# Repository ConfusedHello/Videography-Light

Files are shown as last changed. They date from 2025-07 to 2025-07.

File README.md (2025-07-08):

# LUXCRAFT - DIY Film Light
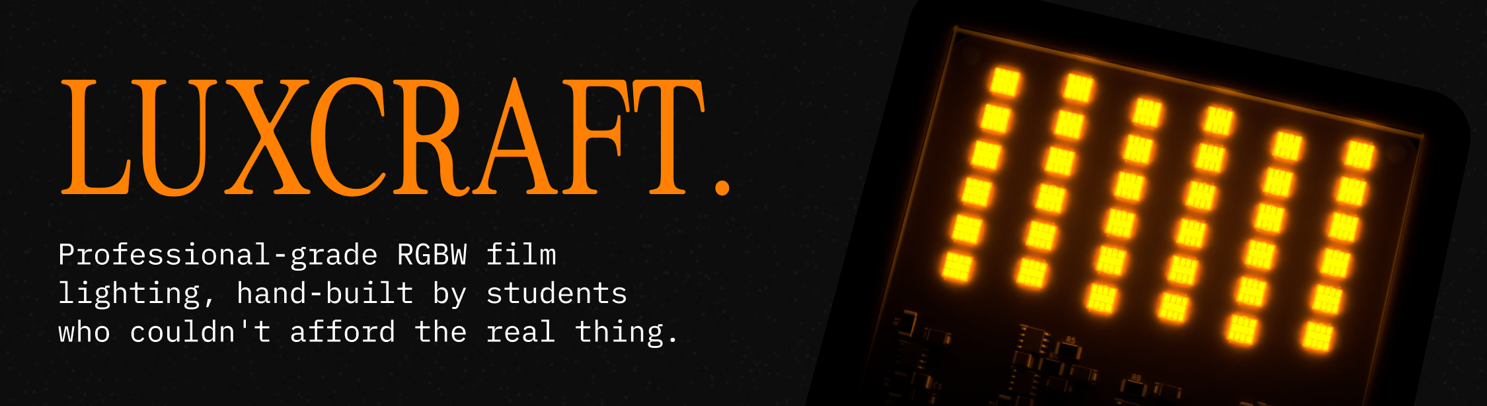
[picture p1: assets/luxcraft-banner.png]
Banner


Ever wanted a videography light but died when seeing the insane prices? Me too! This project involves a DIY, high-power RGBW film light built by [@ConfusedHello](https://github.com/confusedhello) and [@Jayx2u](https://github.com/Jayx2u/) for the Hack Club [Highway to Hardware](https://highway.hackclub.com/) program!

We decided to design this project because as students, we honestly don't have the spare cash lying around for one, and we wanted a nice accent light for our planned upcoming videos. It utilises 36 *current controlled* RGBW LEDs running off a 48V supply and controlled with a Xiao RP2040!

For details about the design process or other information, check out the [development journal](https://highway.hackclub.com/projects/ConfusedHello/Videography-Light). A local copy is available in [JOURNAL.md](https://github.com/ConfusedHello/Videography-Light/blob/main/JOURNAL.md).

## The Design
Here's a quick diagram showing how the project works~
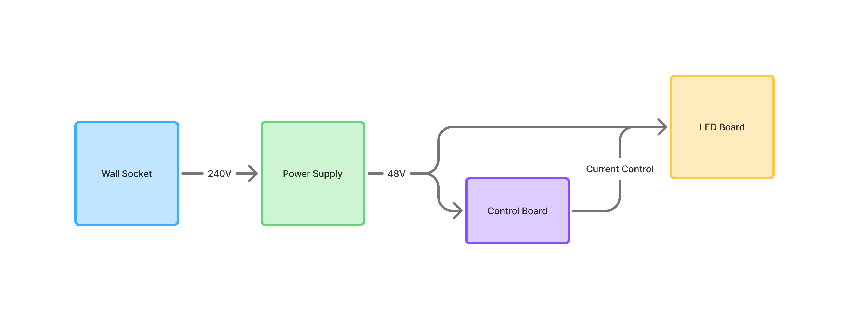
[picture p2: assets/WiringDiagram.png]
Wiring Diagram


And a nice rendered image of the case and control board-
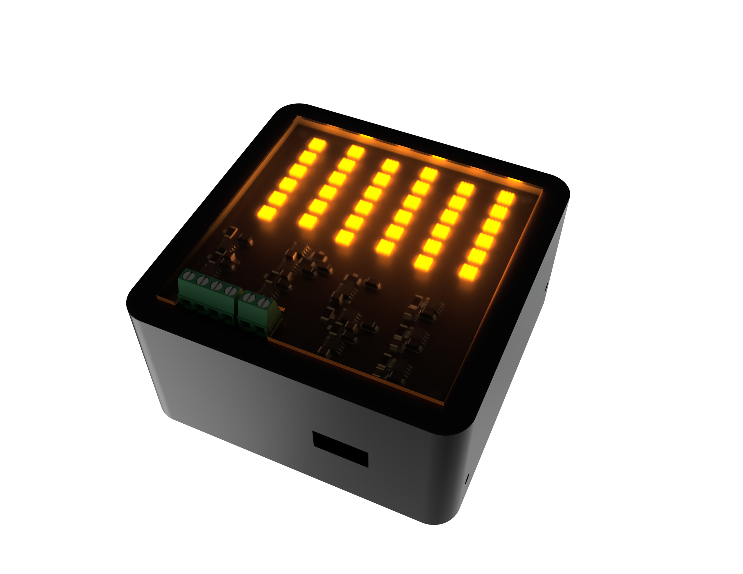
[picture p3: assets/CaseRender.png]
Case Render

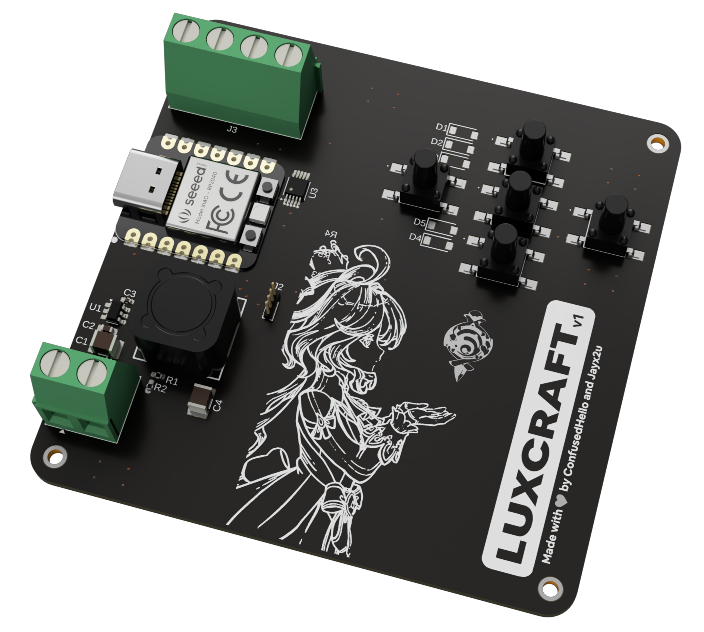
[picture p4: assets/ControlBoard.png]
Control Board


As well as the schematic and PCB for both the control and light boards!
Schematic and PCB for both boards

Also the CAD because apparently that's necessary.
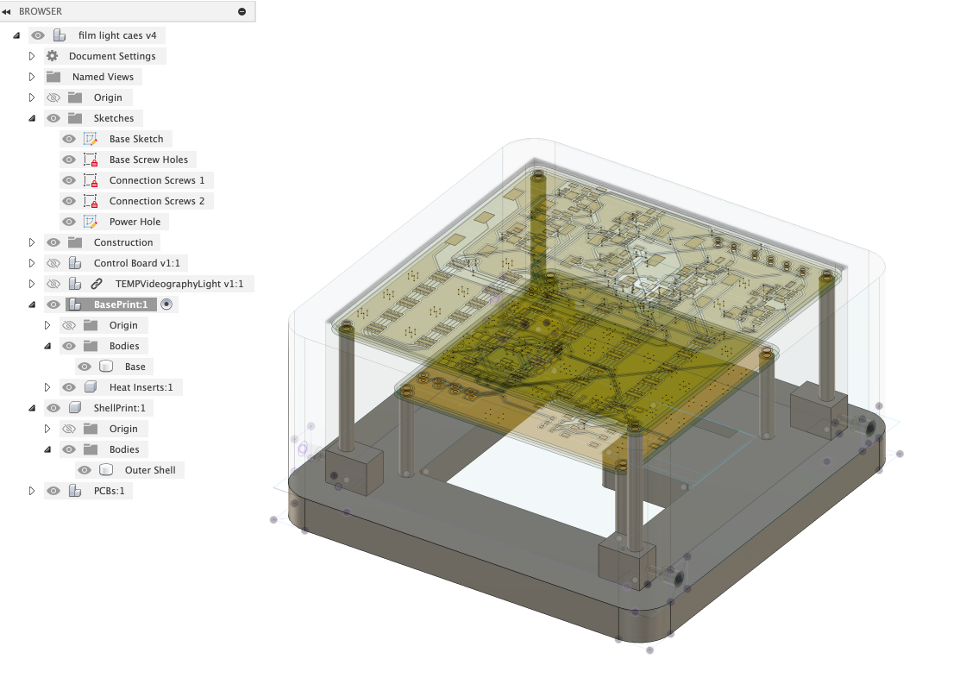
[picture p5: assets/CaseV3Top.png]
CAD
 

## Bill of Materials
Also available in .csv format in [BOM.csv](https://github.com/ConfusedHello/Videography-Light/blob/main/BOM.csv)! BOMs for the PCBs are in [ControlBoard.csv](https://github.com/ConfusedHello/Videography-Light/blob/main/src/Production/Control%20PCB/ControlBoard.csv) and [VideographyLight.csv](https://github.com/ConfusedHello/Videography-Light/blob/main/src/Production/Light%20PCB/VideographyLight.csv)~

|Item |Qty.|Price (USD)|Ext. (USD)|Link |
|---|----|---|---|---|
|997-L1MCRGB2295MP0 |36  |$1.36 |$48.96 |https://mouser.com/c/?q=997-L1MCRGB2295MP0 |
|81-GRM32EC72A106ME5K |11  |$0.71 |$7.85 |https://mouser.com/c/?q=81-GRM32EC72A106ME5K |
|710-7447706101 |11  |$1.01 |$11.11 |https://mouser.com/c/?q=710-7447706101 |
|71-WSLT2010R5000FEA1 |11  |$0.57 |$6.28 |https://mouser.com/c/?q=71-WSLT2010R5000FEA1 |
|625-SS1H10-E3 |11  |$0.28 |$3.11 |https://mouser.com/c/?q=625-SS1H10-E3 |
|621-AL8862SP-13 |11  |$0.54 |$5.93 |https://mouser.com/c/?q=621-AL8862SP-13 |
|179-TB0012-508-04GR |2 |$1.29 |$2.58 |https://mouser.com/c/?q=179-TB0012-508-04GR |
|179-TB0012-508-02GR |2 |$0.69 |$1.38 |https://mouser.com/c/?q=179-TB0012-508-02GR |
|579-MCP4728-E/UN |1 |$2.50 |$2.50 |https://mouser.com/c/?q=579-MCP4728-E/UN |
|713-102010428 |1 |$5.40 |$5.40 |https://mouser.com/c/?q=713-102010428 |
|595-LMR51606XFQDBRQ1 |1 |$2.25 |$2.25 |https://mouser.com/c/?q=595-LMR51606XFQDBRQ1 |
|179-TS046695BK100SMT |5 |$0.16 |$0.80 |https://mouser.com/c/?q=179-TS046695BK100SMT |
|71-CRCW12104K70JNAIF |2 |$0.58 |$1.16 |https://mouser.com/c/?q=71-CRCW12104K70JNAIF |
|71-CRMA1210AF100KFKF |1 |$0.85 |$0.85 |https://mouser.com/c/?q=71-CRMA1210AF100KFKF |
|71-CRCW0402-19.1K-E3 |1 |$0.10 |$0.10 |https://mouser.com/c/?q=71-CRCW0402-19.1K-E3 |
|71-CRCW0402-100K-E3 |1 |$0.10 |$0.10 |https://mouser.com/c/?q=71-CRCW0402-100K-E3 |
|70-IFDC5050JZER470M |1 |$0.96 |$0.96 |https://mouser.com/c/?q=70-IFDC5050JZER470M |
|637-1N4148W |5 |$0.10 |$0.50 |https://mouser.com/c/?q=637-1N4148W |
|810-C3225X7R1H106MAC |2 |$0.96 |$1.92 |https://mouser.com/c/?q=810-C3225X7R1H106MAC |
|81-GRM155R71C104KA88 |2 |$0.10 |$0.20 |https://mouser.com/c/?q=81-GRM155R71C104KA88 |
|81-GRM188R72A104KA35 |1 |$0.15 |$0.15 |https://mouser.com/c/?q=81-GRM188R72A104KA35 |
|581-KAM32LR72A475KU |1 |$0.91 |$0.91 |https://mouser.com/c/?q=581-KAM32LR72A475KU |
|Aluminum Heatsink |10  |$0.73 |$7.33 |https://www.aliexpress.com/item/4000723868050.html |
|0.96 Inch OLED Display |1 |$2.60 |$2.60 |https://www.aliexpress.com/item/1005007614149117.html|
|M2 Heat Insert |16  |$0.11 |$1.73 |https://www.aliexpress.com/item/1005003582355741.html|
|M2 Screw (10mm) |16  |$0.21 |$3.40 |https://www.aliexpress.com/item/1005005688616965.html|
|48V Power Supply |1 |$25.73 |$25.73 |https://www.aliexpress.com/item/1005008528926877.html|
|JLCPCB Control Board |1 |$2.00 |$2.00 |https://www.jlcpcb.com |
|JLCPCB Light Board |1 |$2.00 |$2.00 |https://www.jlcpcb.com |
|JLCPCB Light Board Stencil|1 |$7.00 |$7.00 |https://www.jlcpcb.com |
|JLCPCB Shipping |1 |$21.22 |$21.22 |https://www.jlcpcb.com |

**Total:** $178.01 USD

<hr>

Made with ❤️ by [@ConfusedHello](https://github.com/confusedhello) and [@Jayx2u](https://github.com/Jayx2u/)

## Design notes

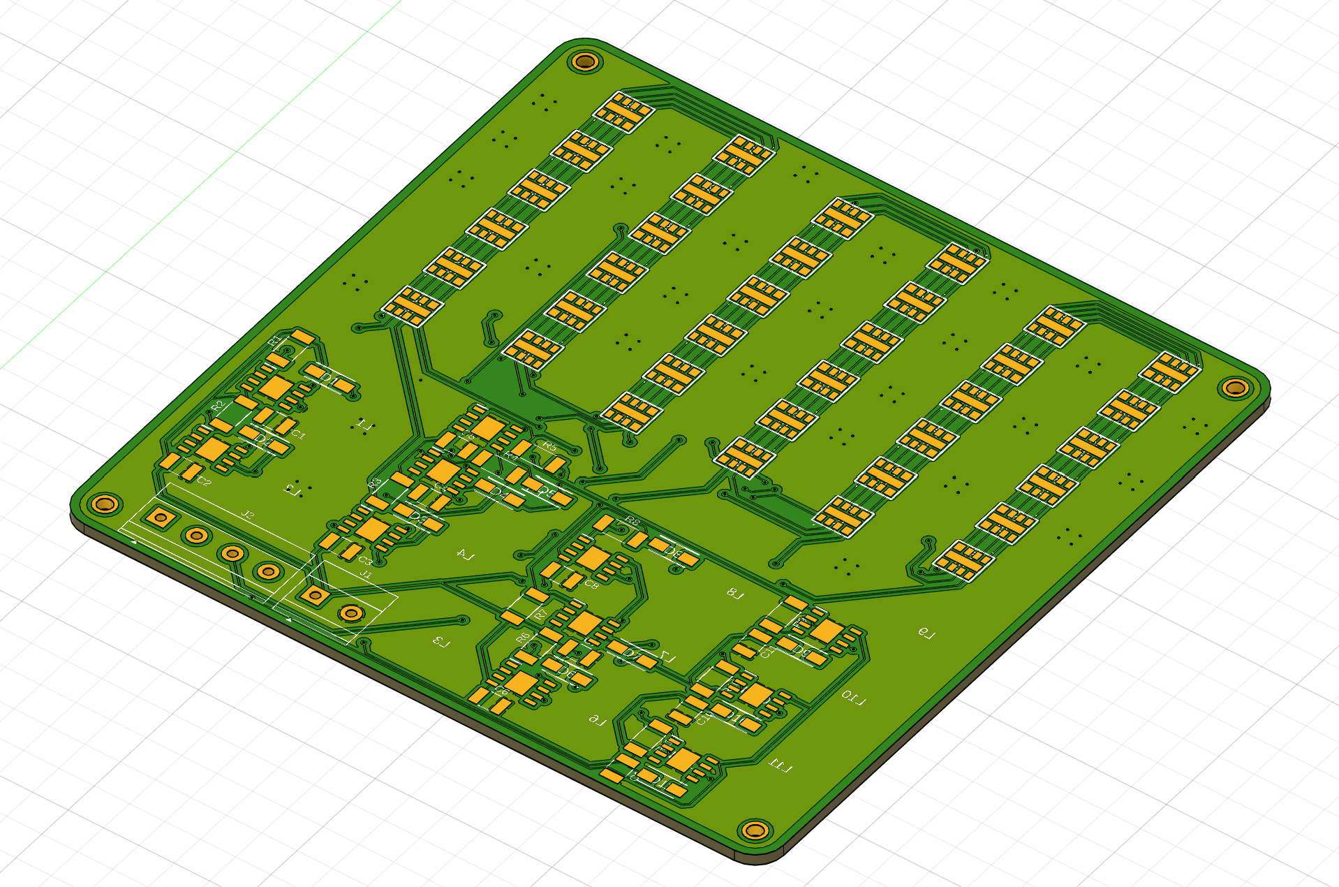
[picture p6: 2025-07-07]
assets/FusionPCB1.png

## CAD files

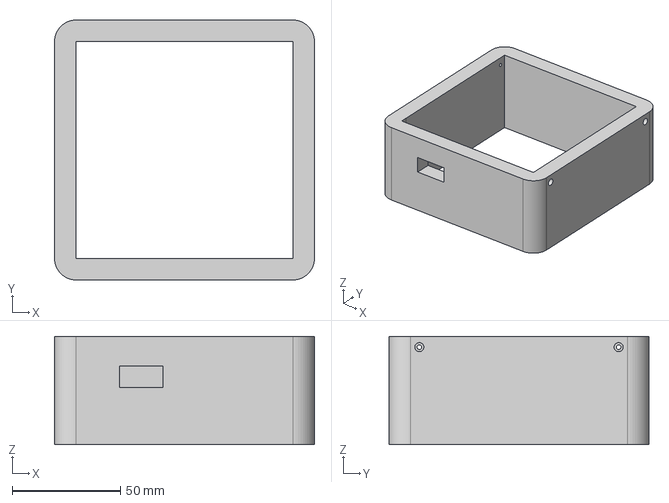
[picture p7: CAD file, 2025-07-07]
src/CAD/ShellPrint.step
120.0 x 120.0 x 50.0 mm

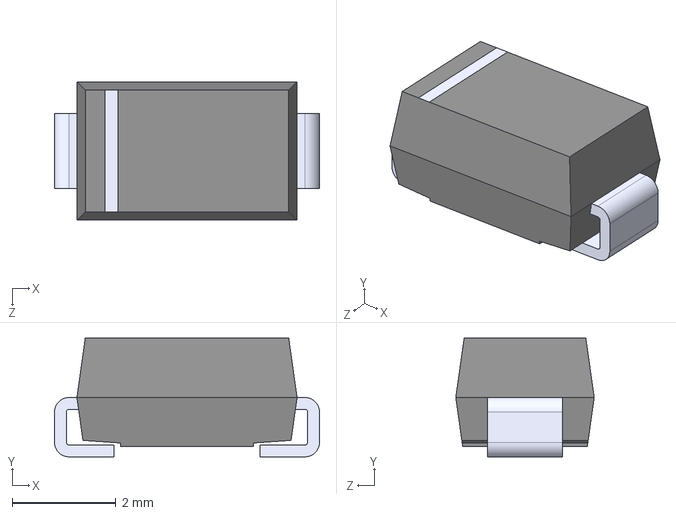
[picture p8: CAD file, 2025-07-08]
src/PCB/VideographyLight/footprints/models/SS1H10-E3_61T.stp
5.11 x 2.29 x 2.67 mm

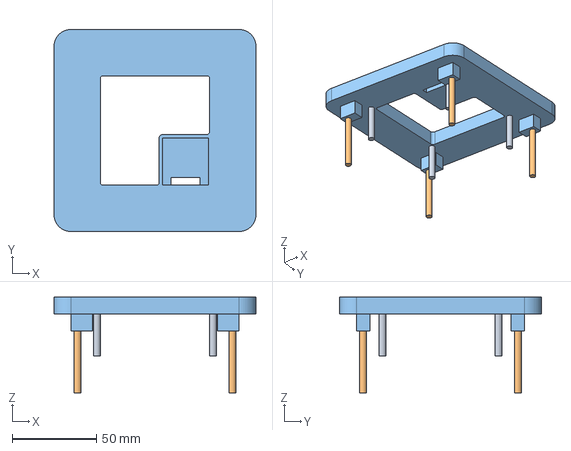
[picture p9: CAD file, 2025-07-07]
src/CAD/BasePrint.step
120.0 x 120.0 x 56.9 mm

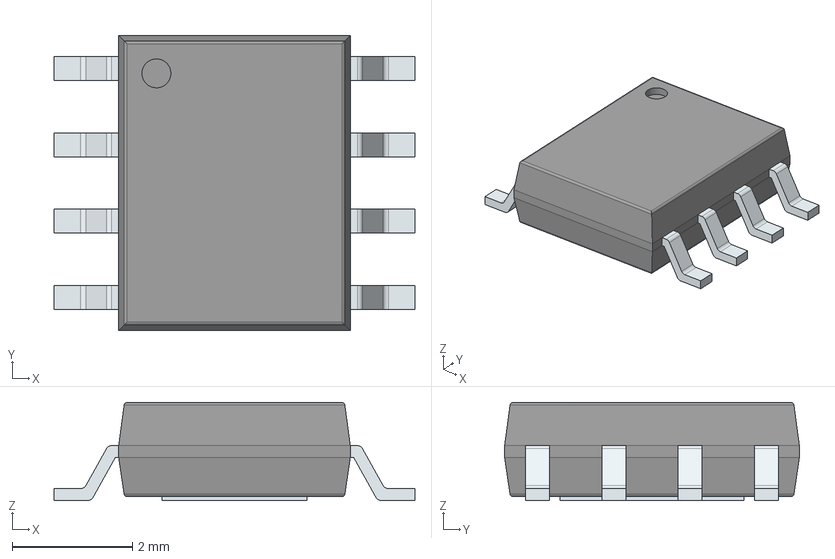
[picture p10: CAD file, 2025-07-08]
src/PCB/VideographyLight/footprints/models/AL8862SP-13.stp
6.00 x 4.90 x 1.63 mm
PinsArrayLR
ThermalPad

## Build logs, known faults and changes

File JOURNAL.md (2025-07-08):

---
title: "Videography Light"
author: "ConfusedHello, Jayx2u"
description: "A DIY Film Light for Videography!"
created_at: "2025-06-29"
---

**Total time spent: 66hrs**

## July 8th
Final preparations for submission! Did some silkscreening for the control PCB, made a quick flowchart for the wiring, finished up the BOM, rendered out some nice images for the README, and well, wrote the README all in time for a note-so-late night submission (woah not 1AM really?).

**Time spent: 7hrs**

## July 7th - @Jayx2u
With the PCB design completed, it was time for the case. I had the incredibly innovative never-seen before idea of placing a cube (with round corners of course) around all the electronics and calling it a day. Shocking and genius idea I know right, no need to thank me. ;)

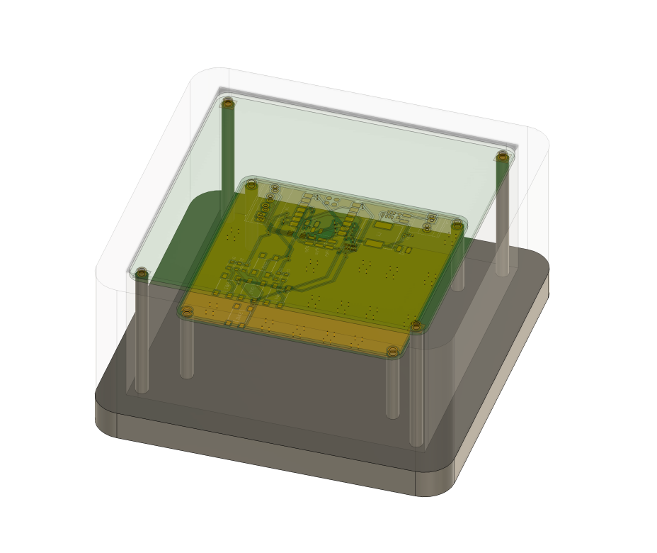
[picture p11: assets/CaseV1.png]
Case v1

Annnnnd volia! A cube around the whole thing. Has ample space for all the components and the heatsink. The translucent component is the shell and the rest is the base. Printed in to different parts. 

Then it hits me 🤸🏌️. How do I attach the base to the shell??? So voila again, version 2, but with four screw holes in the shell and 4 heat insert areas on the base.

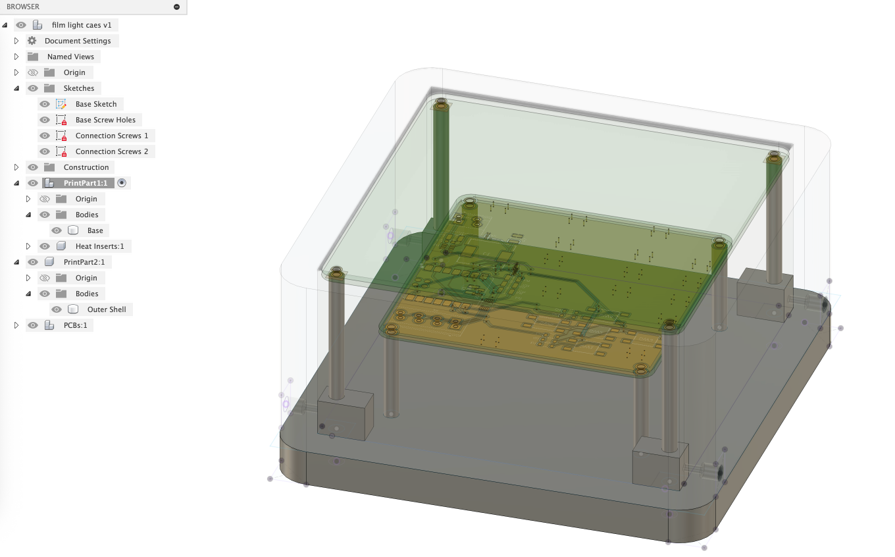
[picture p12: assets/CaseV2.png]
Case v2


Then it runs into me (again I know) 🤸🚗. How do I access the buttons on the bottom of the control PCB? Where's the OLED screen's location?? How does the power cables go into the case and connect to the control PCB??? So onto version 3 (aka final-final-this-time-for-real-film-light-caes.f3d). I decided to just put a hole in the bottom (with curved edges of course) and also include the place the OLED will be down there too. Also put a hole in the side for the power cables to enter. Here is what the base sketch ended up looking like - wanted it very precise:

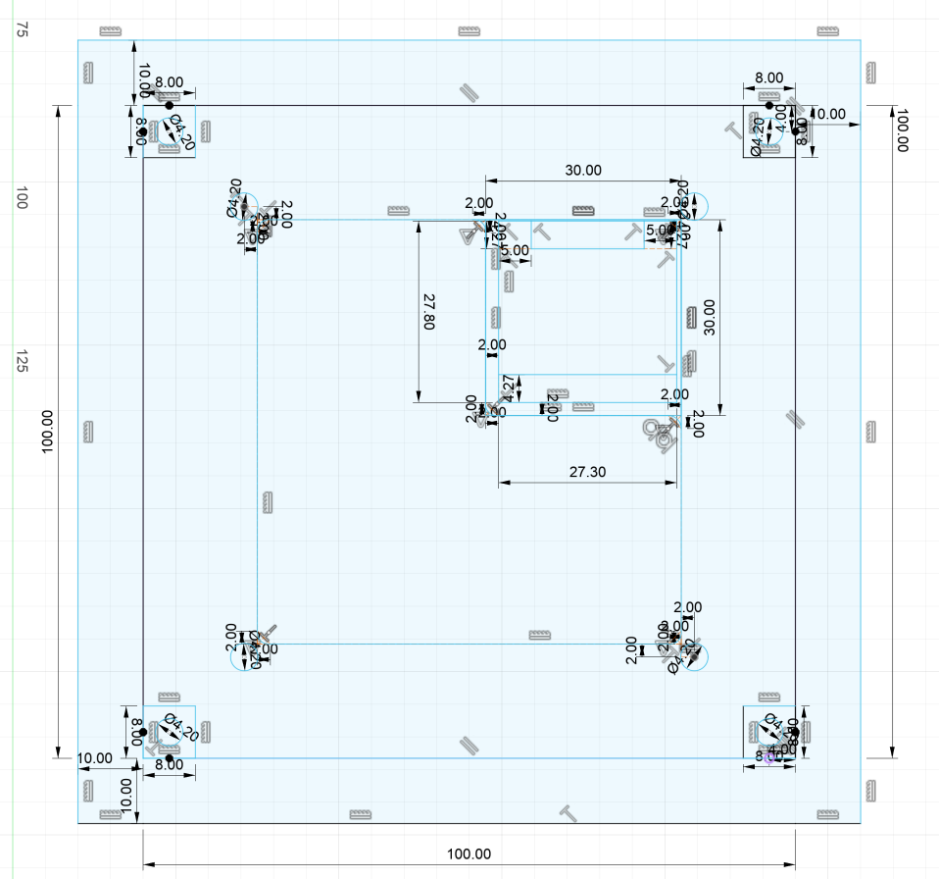
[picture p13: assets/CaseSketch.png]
Case Sketch


And with that.... tadaaaa version 3:

Case v3 Top
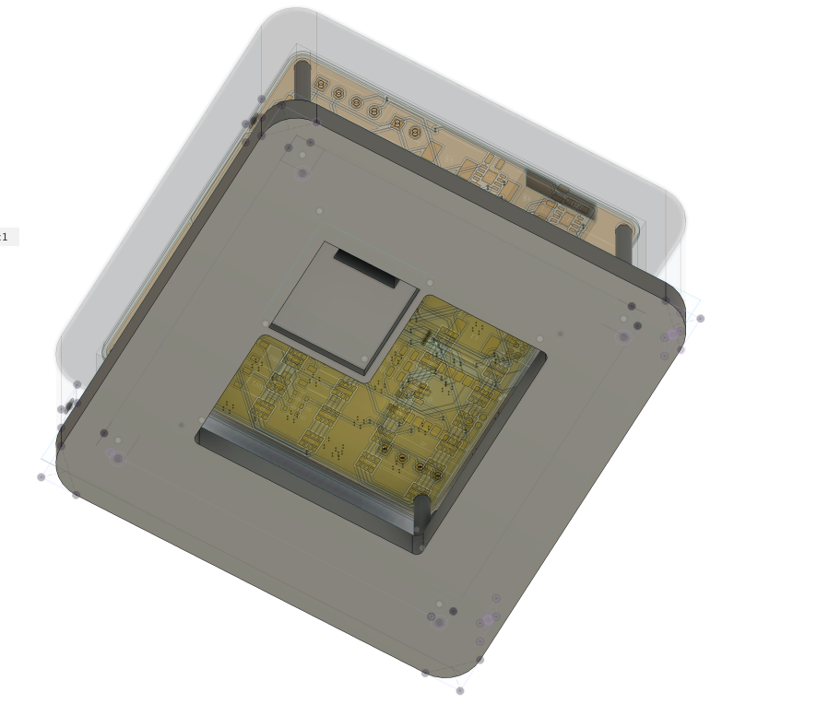
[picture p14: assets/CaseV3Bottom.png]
Case v3 Bottom


**Time spent: 2hrs**

## July 3rd, 4th, 7th - @ConfusedHello
Finished off the light PCB!! Here's some screenshots to conclude my development journaling! There's actually better images in the [README](https://raw.githubusercontent.com/ConfusedHello/Videography-Light/) with silkscreens~

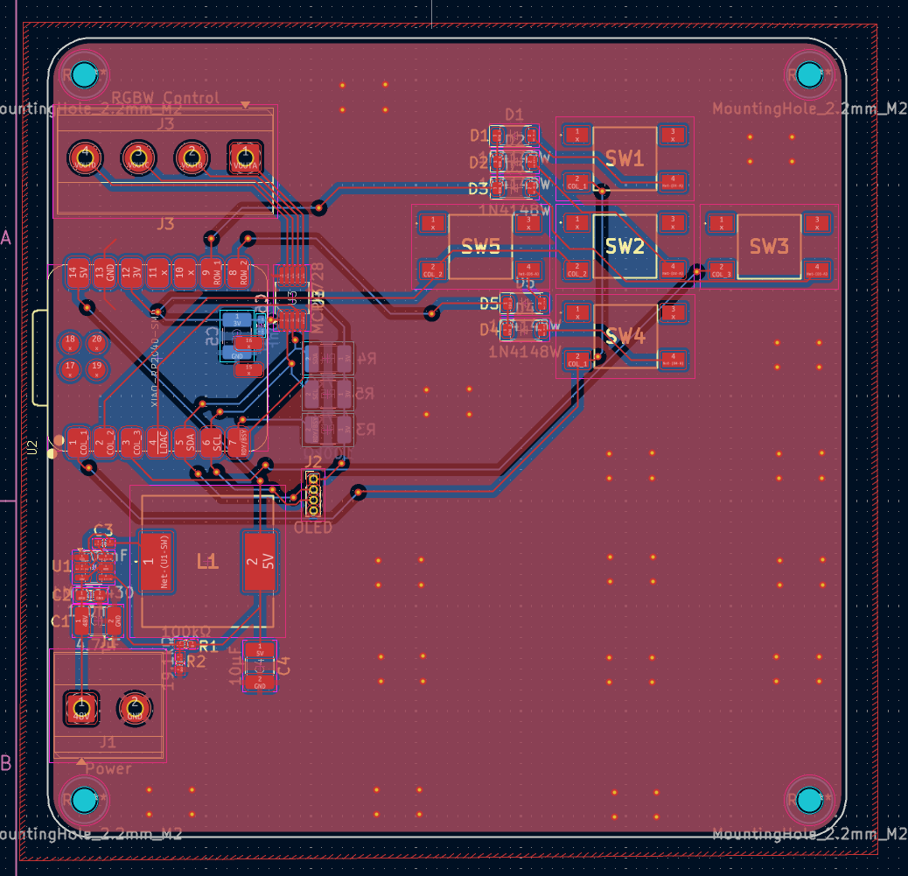
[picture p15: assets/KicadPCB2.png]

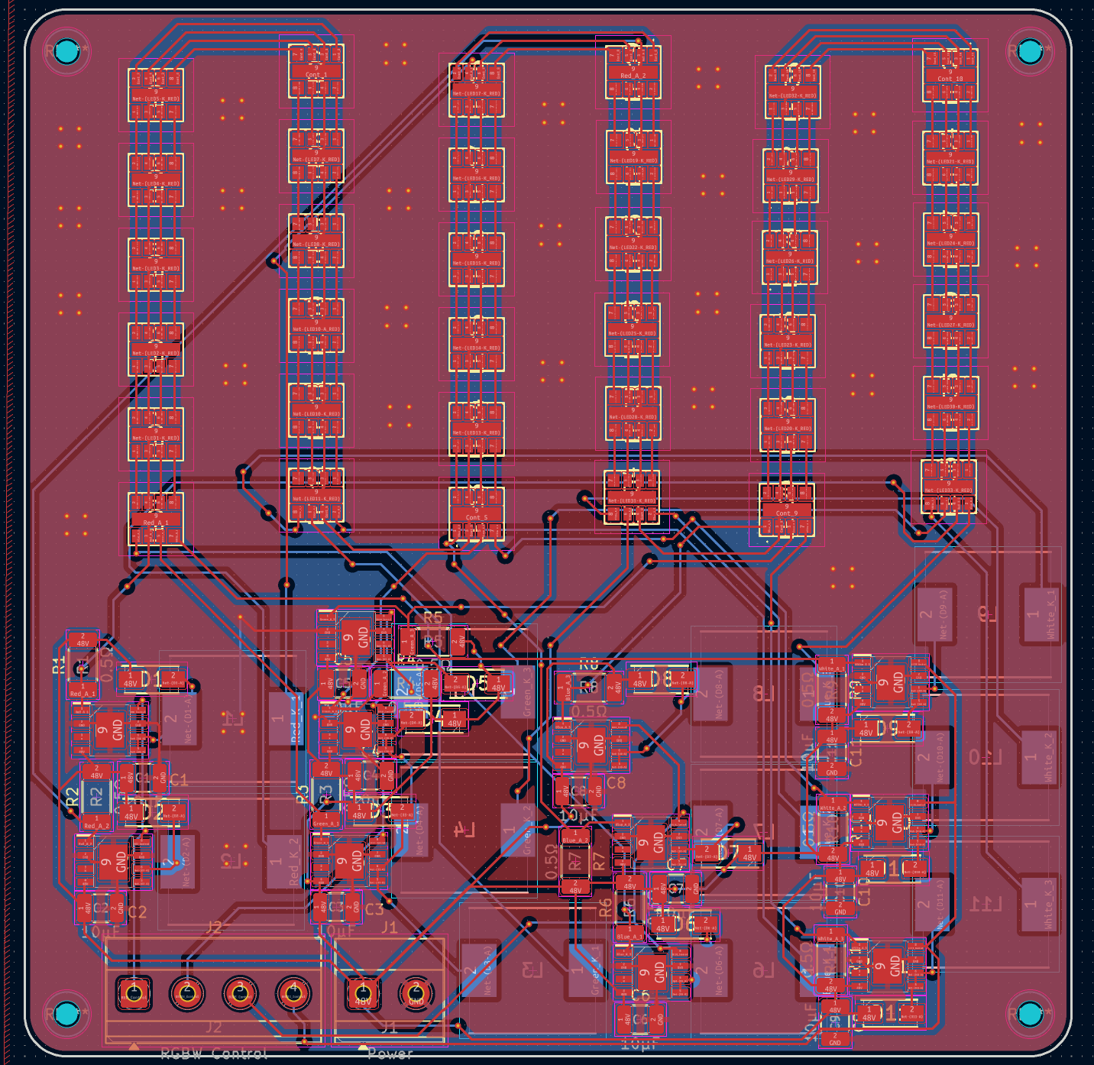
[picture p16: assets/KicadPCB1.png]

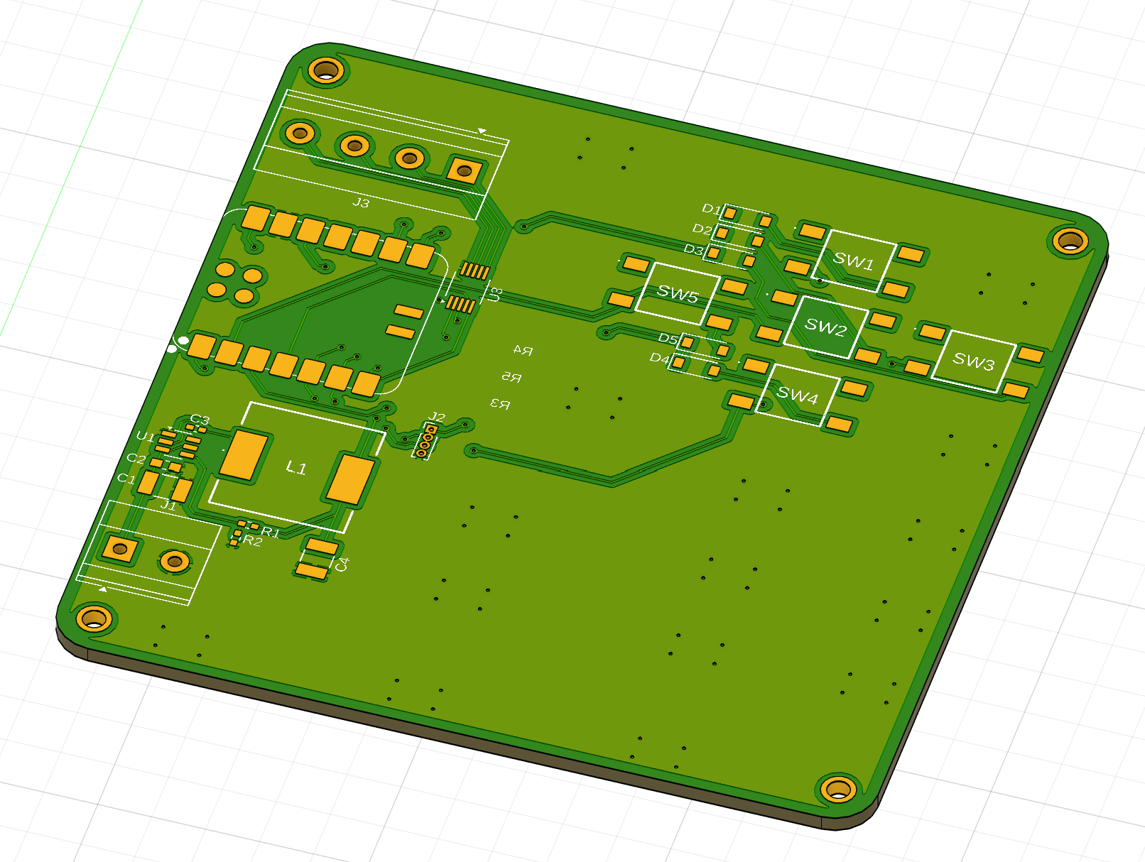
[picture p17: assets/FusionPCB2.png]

PCB

Finishing off the PCB was not particularly easy but it (hopefully) should be functional! Here's some crazy routing (with the GND plane removed)

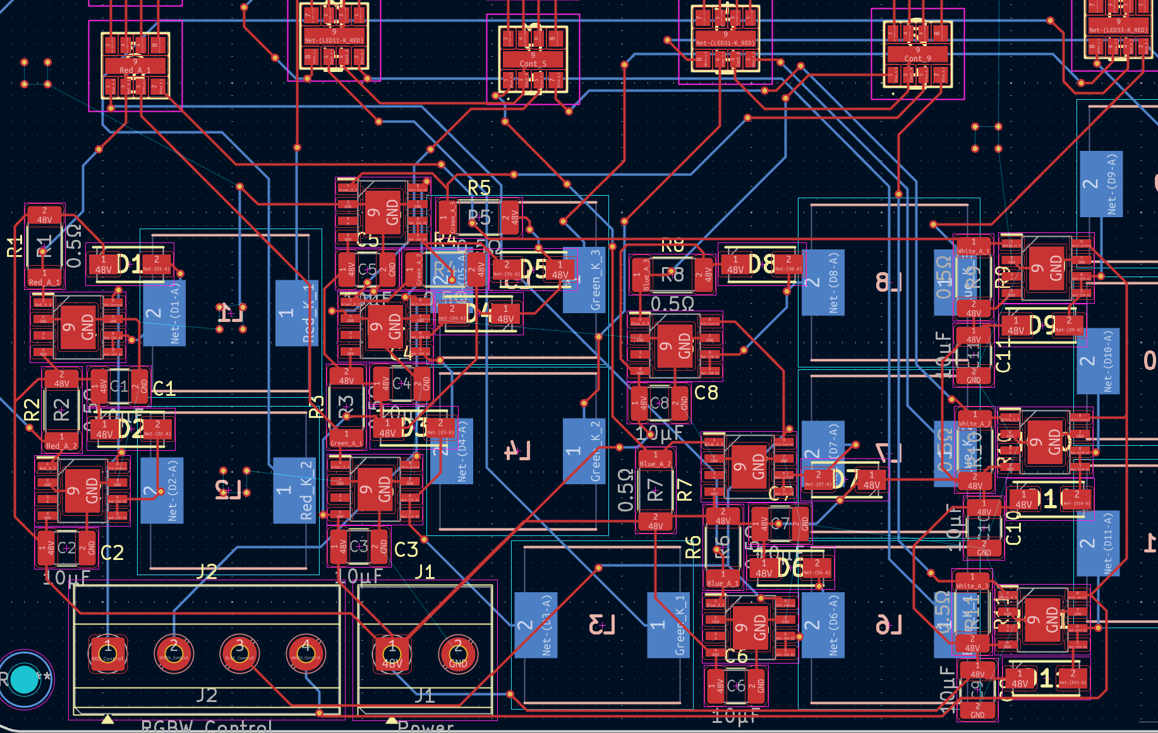
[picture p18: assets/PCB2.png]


**Time spent: 22hrs**

## July 2nd - @ConfusedHello
Another full day spent on the project - practically the entire day from waking up to going to sleep. Made the control board schematic and PCB today!

The control board will use a XIAO RP2040 MCU, along with a DAC for precise RGBW intensity control (voltage control). The PCB layout for this board was honestly not the worst I've done. There's also a 5V regulator circuit for the MCU and DAC.

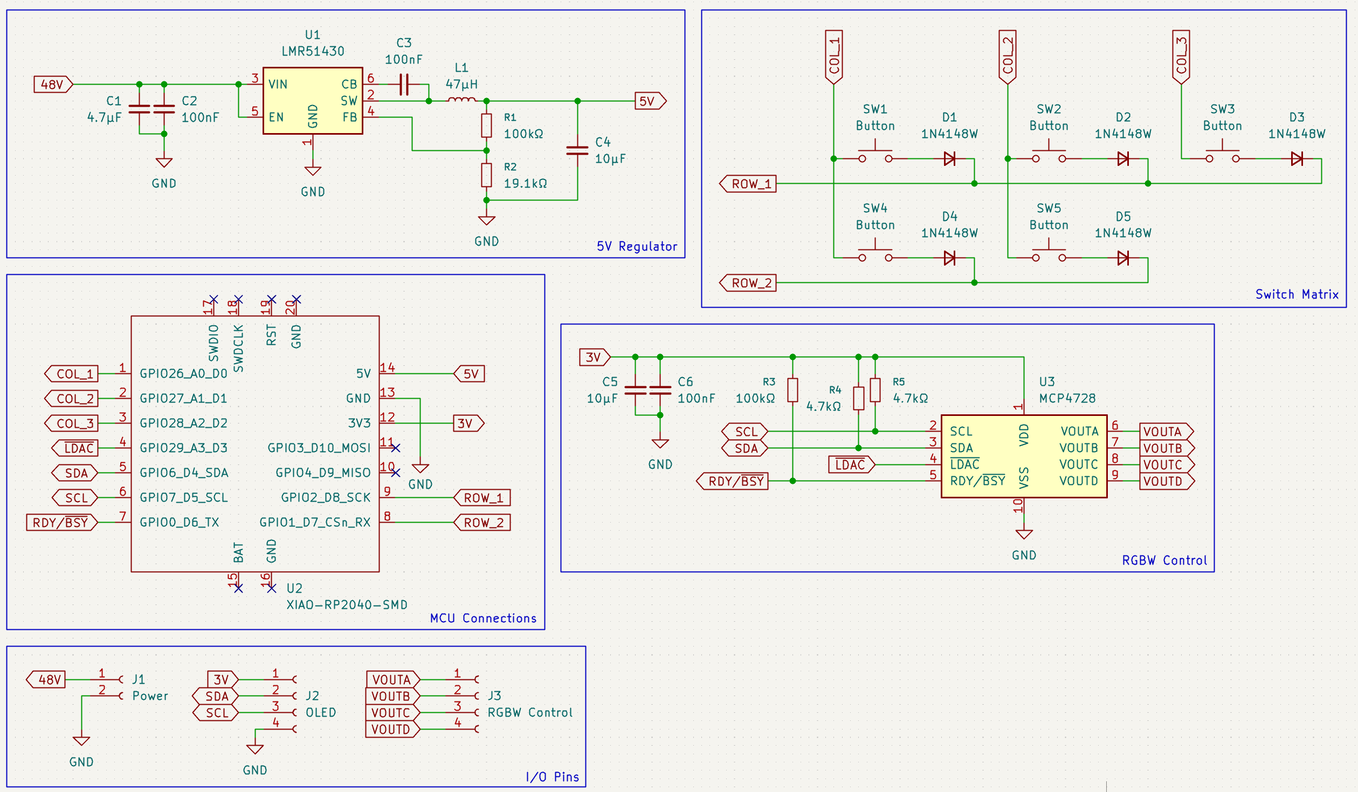
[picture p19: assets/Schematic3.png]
Schematic

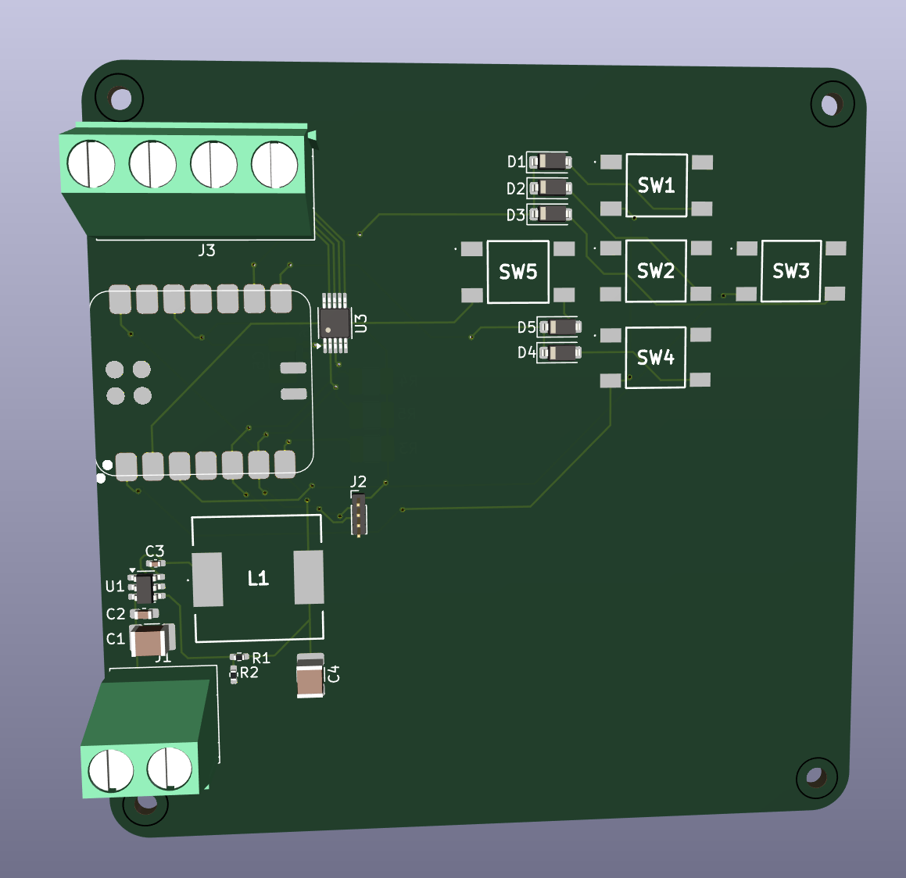
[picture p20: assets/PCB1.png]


Also managed to write the software for the MCU today now available in [\src\Software](https://github.com/ConfusedHello/Videography-Light/tree/main/src/Software)

**Time spent: 14hrs**

## June 30th / July 1st - @ConfusedHello
Journaling two days at once here (mostly because I was up until 2am looking at plane tickets) but as a quick summary of what's happened the last two days (would prefer nice, longer journals but timeee), the initial research involved looking at current commercial products and planning a little into how we're going to do this. A few things we looked at include:

- Important information about film lights! This includes brightness, CRI, DMX. One important spec is the Color Rendering Index which determines the accuracy of skin tone under the light. Typical film lights are ~96CRI.
- RGBW LEDs! I think I've settled on the [Lumileds L1MC-RGB2290500MP0](https://au.mouser.com/ProductDetail/Lumileds/L1MC-RGB2290500MP0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) for their 90CRI (not particularly good for filming but still better than all the other 70-80CRI ones). The 2200K (warm white) temperature isn't *the best* but I imagine we can get around that by utilising the RGB colours more when going for a cool lighting and utilising the white more when shooting warm.
- LED drivers! From the looks of it there doesn't actually seem to be all that many for me to choose from that support the max ~200mA current but 120mA I<sub>f</sub> should do okay (this is the max for the drivers I've found). The [TLC59116](https://www.ti.com/product/TLC59116) should be okay for this project.
- The case and stand I'm leaving the @Jayx2u - they'll be designing the case, as well as the mounting solution for the light and other misc. components (such as fins).

A lot more research later the setup will most likely be 36 LED packages per board (6x6 grid) and current controlled from 48V, continuing on with the research, A LOT of things were scrapped in the process such as suitable DC/DC buck converters (for 3.3V and 4.5V) when looking at parallel LED drivers before landing on the current (simplified), more efficient solution: driving the LEDs directly from a 48V supply with current control. This high-voltage approach minimizes current requirements, while also reducing trace widths on the PCB.

Considering that we have a 48V supply let's calculate the amount of chips we'll need to power this board.

48V supply for 36 LED packages (6x6 matrix)

LED specs:
```
Red - 200mA @ 2.25V drop
Green - 200mA @ 3.55V drop
Blue - 200mA @ 3.3V drop
White - 200mA @ 3.3V drop
```

2.25 x 36 = 81V drop
... 2 channels (40.5V drop each)

3.55 x 36 = 127.8V drop
... 3 channels (42.3V drop each)

3.3 x 36 = 118.8V drop
... 3 channels (39.6V drop each)

After wiring it up in KiCad:
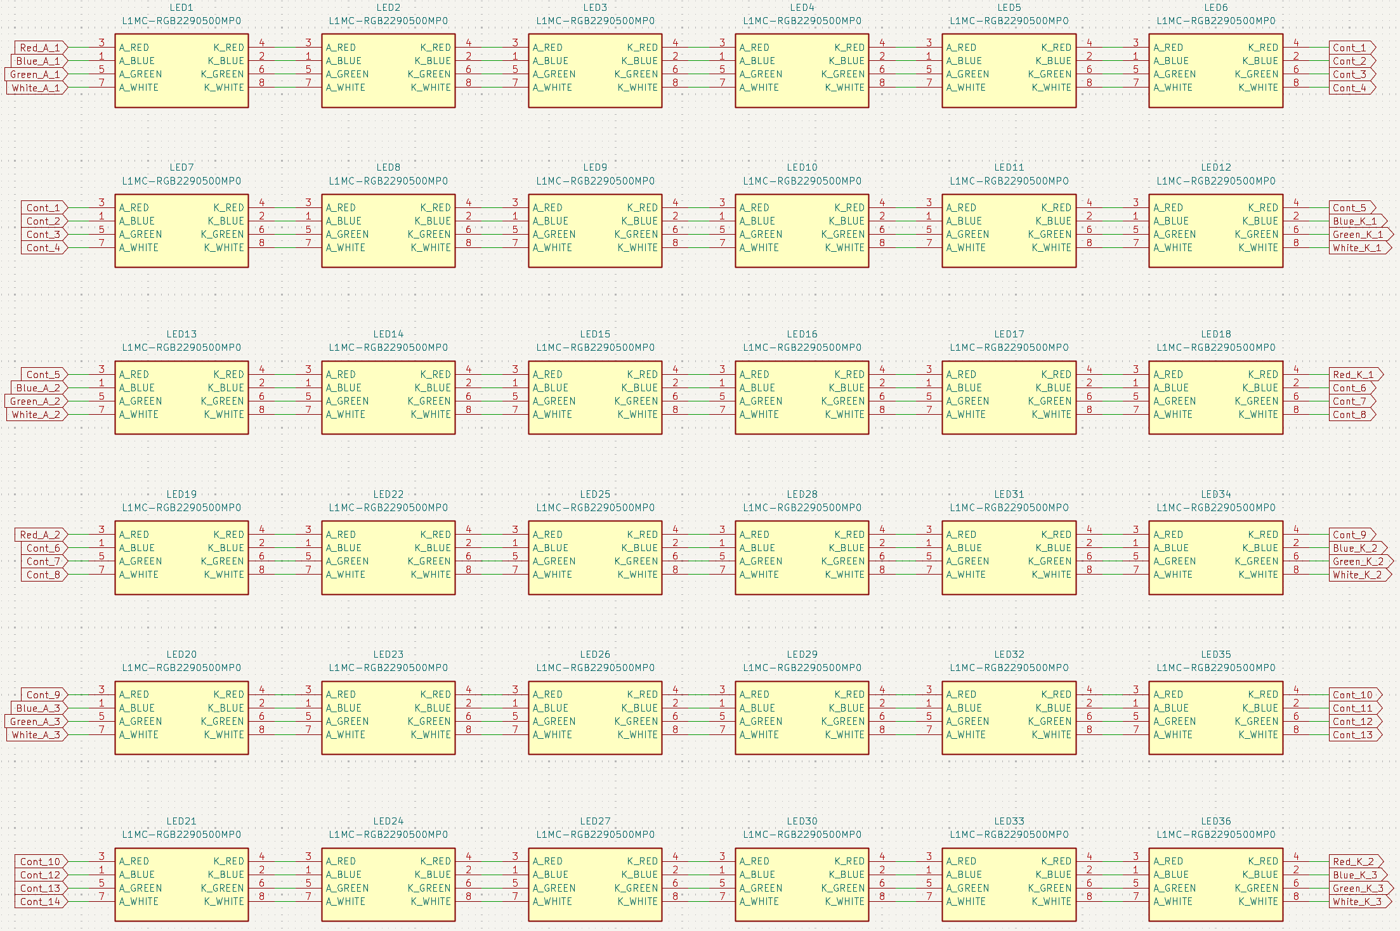
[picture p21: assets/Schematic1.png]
Schematic


And the controllers:
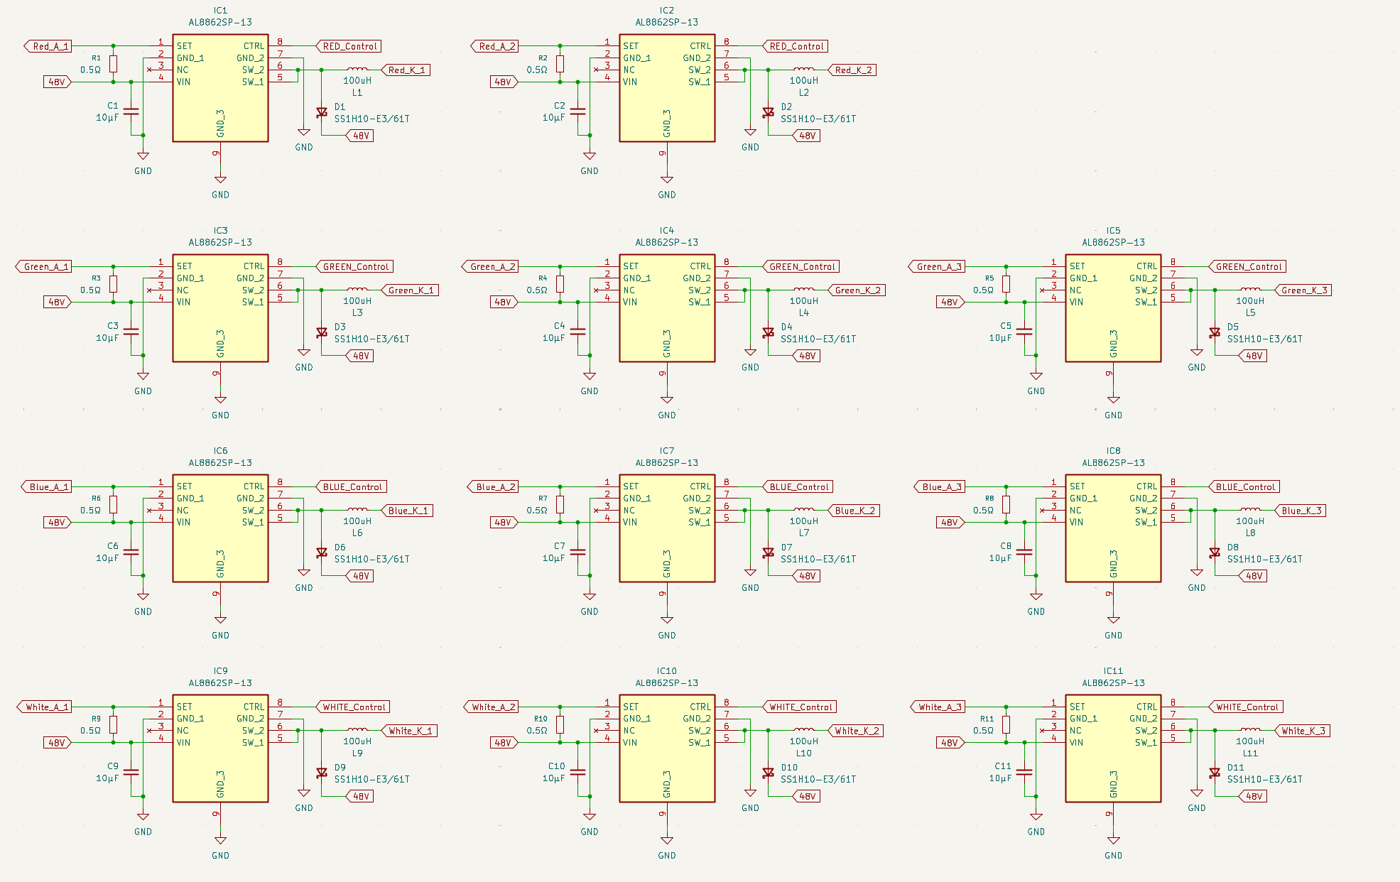
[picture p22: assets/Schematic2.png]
Schematic


Will speedrun the rest of the schematic and PCB tomorrow maybe? Time to finish up for today though as it's almost 1AM.

**Time spent: 18hrs**

## June 29th - @ConfusedHello
It's 2AM in the morning and ~~I'm calling you now~~ making a new Git repo! Today was some initial research to determine if the project was achievable and some other general information relating to the project. Also, happy to bring @Jayx2u onboard this time! We'll be working on this project realistically over the next two weeks to (hopefully) make a decent film light for our planned upcoming video!

**Time spent: 3hrs**

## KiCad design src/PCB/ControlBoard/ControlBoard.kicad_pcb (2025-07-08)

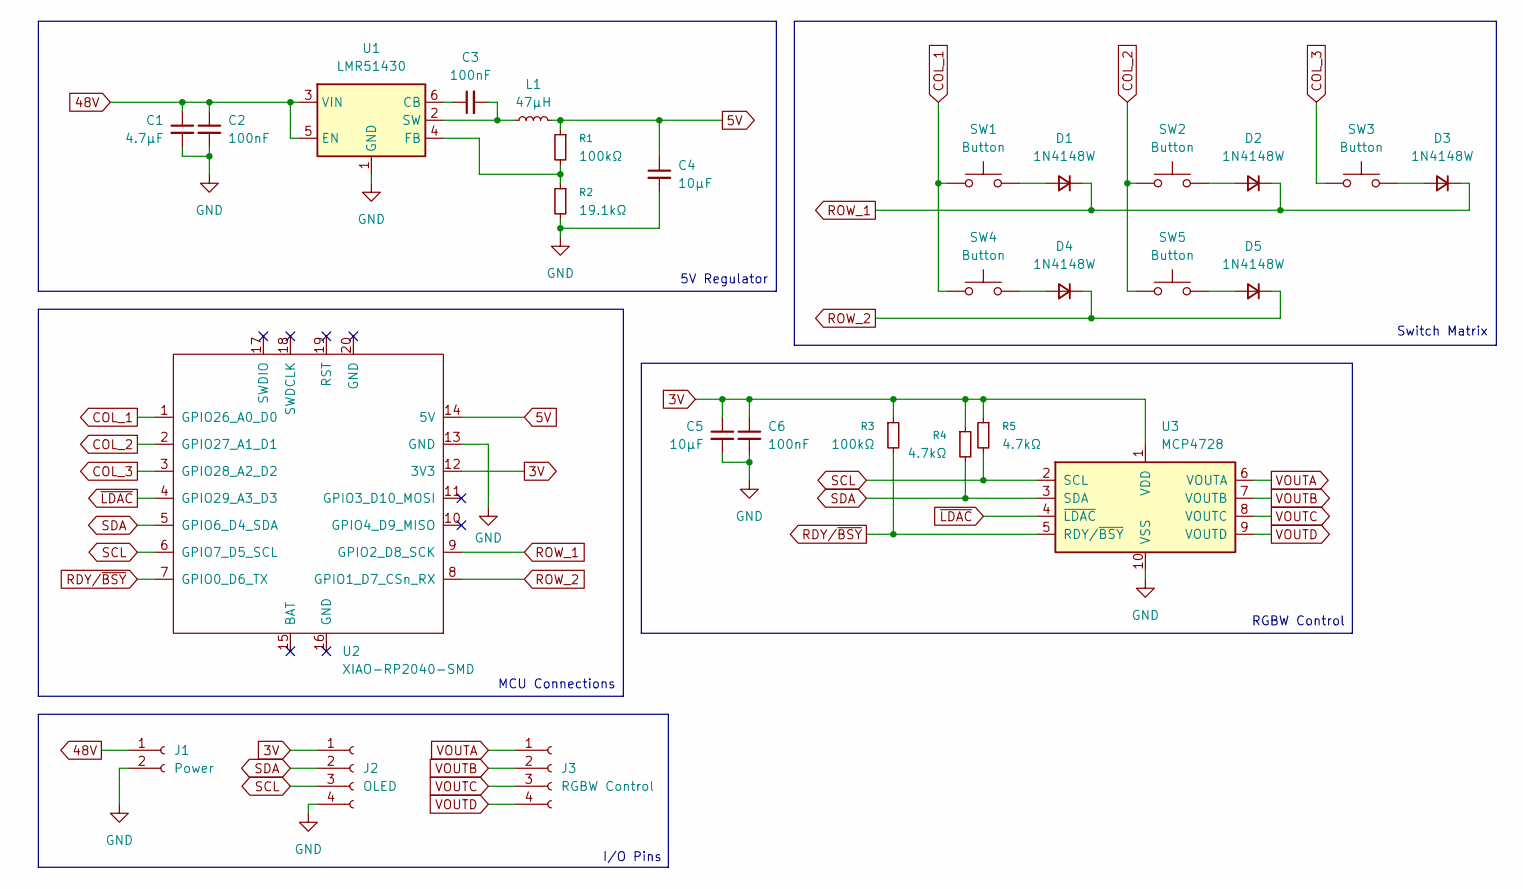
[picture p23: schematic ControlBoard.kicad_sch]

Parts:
C1: 4.7μF; C_1210_3225Metric_Pad1.33x2.70mm_HandSolder; Mouser 581-KAM32LR72A475KU
C2: 100nF; C_0603_1608Metric_Pad1.08x0.95mm_HandSolder; Mouser 81-GRM188R72A104KA35
C3, C6: 100nF; C_0402_1005Metric_Pad0.74x0.62mm_HandSolder; Mouser 81-GRM155R71C104KA88
C4, C5: 10μF; C_1210_3225Metric_Pad1.33x2.70mm_HandSolder; Mouser 810-C3225X7R1H106MAC
D1, D2, D3, D4, D5: 1N4148W; D_SOD-123; Mouser 637-1N4148W
J1: Power; TerminalBlock_Phoenix_MKDS-1,5-2-5.08_1x02_P5.08mm_Horizont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; Mouser 179-TB0012-508-02GR
J2: OLED; PinHeader_1x04_P1.00mm_Vertical
J3: RGBW Control; TerminalBlock_Phoenix_MKDS-1,5-4-5.08_1x04_P5.08mm_Horizont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; Mouser 179-TB0012-508-04GR
L1: 47μH; IFDC5050JZER470M; Mouser 70-IFDC5050JZER470M
R1: 100kΩ; R_0402_1005Metric_Pad0.72x0.64mm_HandSolder; Mouser 71-CRCW0402-100K-E3
R2: 19.1kΩ; R_0402_1005Metric_Pad0.72x0.64mm_HandSolder; Mouser 71-CRCW0402-19.1K-E3
R3: 100kΩ; R_1210_3225Metric_Pad1.30x2.65mm_HandSolder; Mouser 71-CRMA1210AF100KFKF
R4, R5: 4.7kΩ; R_1210_3225Metric_Pad1.30x2.65mm_HandSolder; Mouser 71-CRCW12104K70JNAIF
SW1, SW2, SW3, SW4, SW5: Button; TS046695BK100SMT; Mouser 179-TS046695BK100SMT
U1: LMR51430; SOT-23-6; Mouser 595-LMR51606XFQDBRQ1
U2: XIAO-RP2040-SMD; Mouser 713-102010428
U3: MCP4728; MSOP-10_3x3mm_P0.5mm; Mouser 579-MCP4728-E/UN

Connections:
3V: C5.1, C6.1, J2.1, R3.1, R4.1, R5.1, U2.12 (3V3), U3.1 (VDD)
5V: C4.1, L1.2, R1.1, U2.14 (5V)
48V: C1.1, C2.1, J1.1, U1.3 (VIN), U1.5 (EN)
COL_1: SW1.2 (COM_1), SW4.2 (COM_1), U2.1 (GPIO26_A0_D0)
COL_2: SW2.2 (COM_1), SW5.2 (COM_1), U2.2 (GPIO27_A1_D1)
COL_3: SW3.2 (COM_1), U2.3 (GPIO28_A2_D2)
GND: C1.2, C2.2, C4.2, C5.2, C6.2, J1.2, J2.4, R2.2, U1.1 (GND), U2.13 (GND), U3.10 (VSS)
unnamed: D1.2 (A), SW1.4 (COM_2)
unnamed: D2.2 (A), SW2.4 (COM_2)
unnamed: D3.2 (A), SW3.4 (COM_2)
unnamed: D4.2 (A), SW4.4 (COM_2)
unnamed: D5.2 (A), SW5.4 (COM_2)
unnamed: C3.1, U1.6 (CB)
unnamed: R1.2, R2.1, U1.4 (FB)
unnamed: C3.2, L1.1, U1.2 (SW)
RDY/~BSY: R3.2, U2.7 (GPIO0_D6_TX), U3.5 (RDY/~BSY)
ROW_1: D1.1 (K), D2.1 (K), D3.1 (K), U2.9 (GPIO2_D8_SCK)
ROW_2: D4.1 (K), D5.1 (K), U2.8 (GPIO1_D7_CSn_RX)
SCL: J2.3, R5.2, U2.6 (GPIO7_D5_SCL), U3.2 (SCL)
SDA: J2.2, R4.2, U2.5 (GPIO6_D4_SDA), U3.3 (SDA)
VOUTA: J3.1, U3.6 (VOUTA)
VOUTB: J3.2, U3.7 (VOUTB)
VOUTC: J3.3, U3.8 (VOUTC)
VOUTD: J3.4, U3.9 (VOUTD)
~LDAC: U2.4 (GPIO29_A3_D3), U3.4 (~LDAC)

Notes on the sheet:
RGBW Control
5V Regulator
Switch Matrix
MCU Connections
I/O Pins

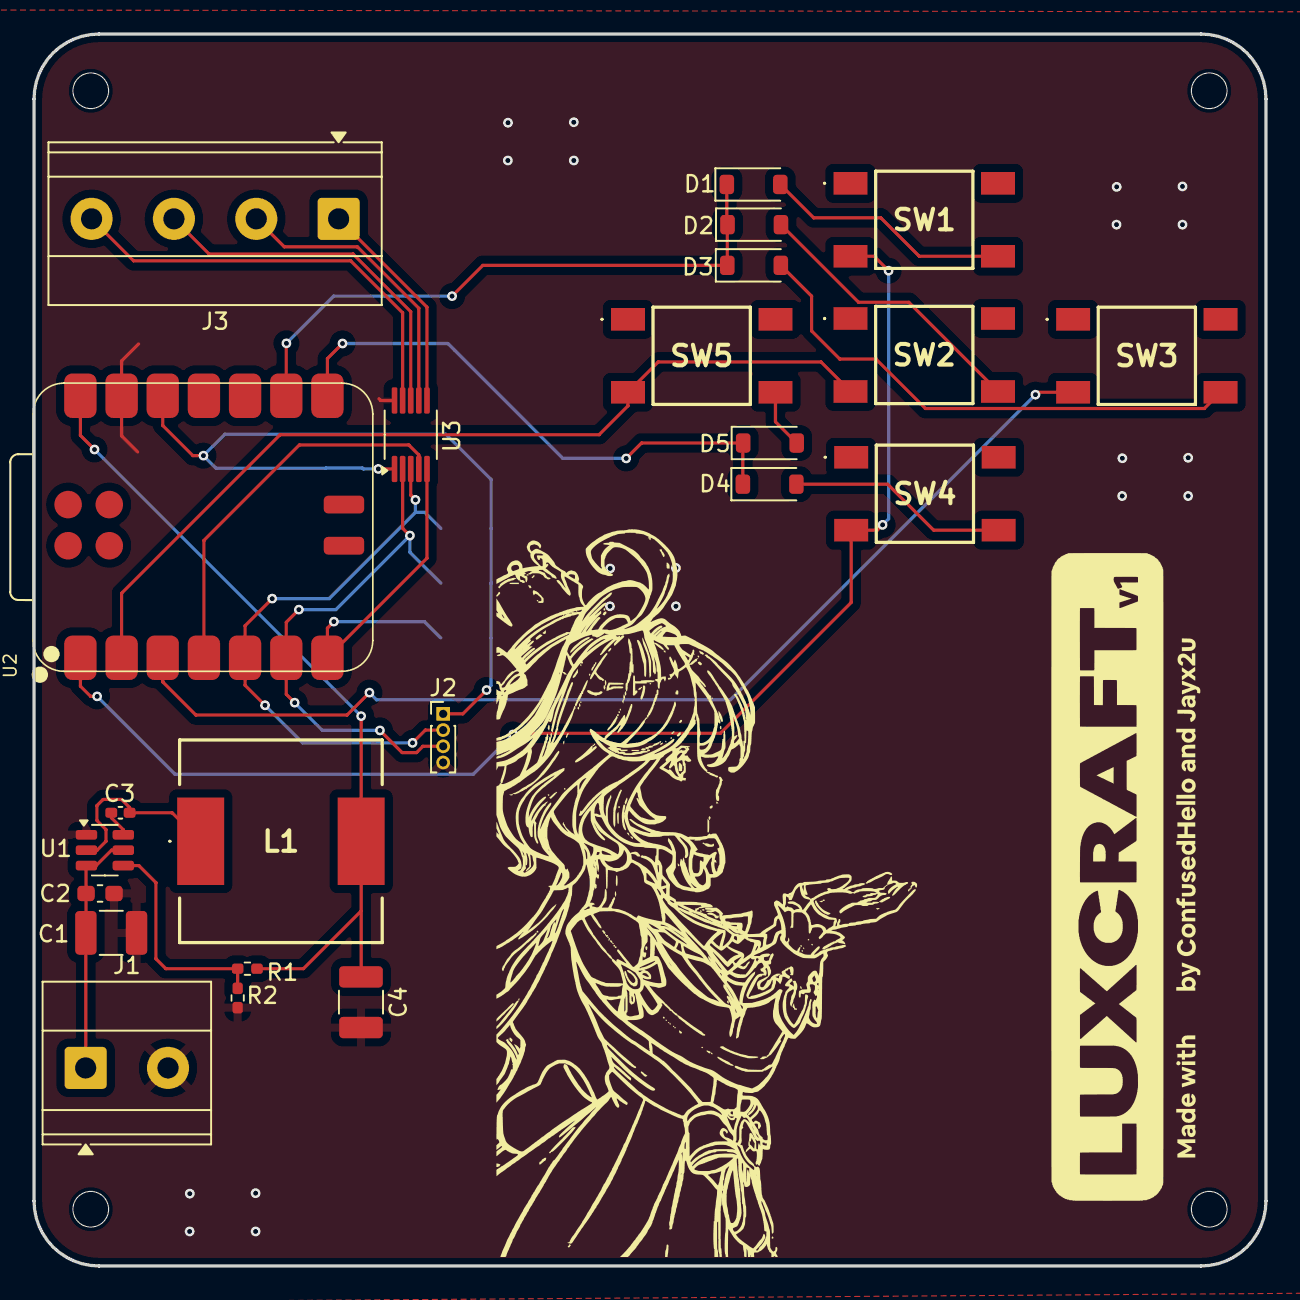
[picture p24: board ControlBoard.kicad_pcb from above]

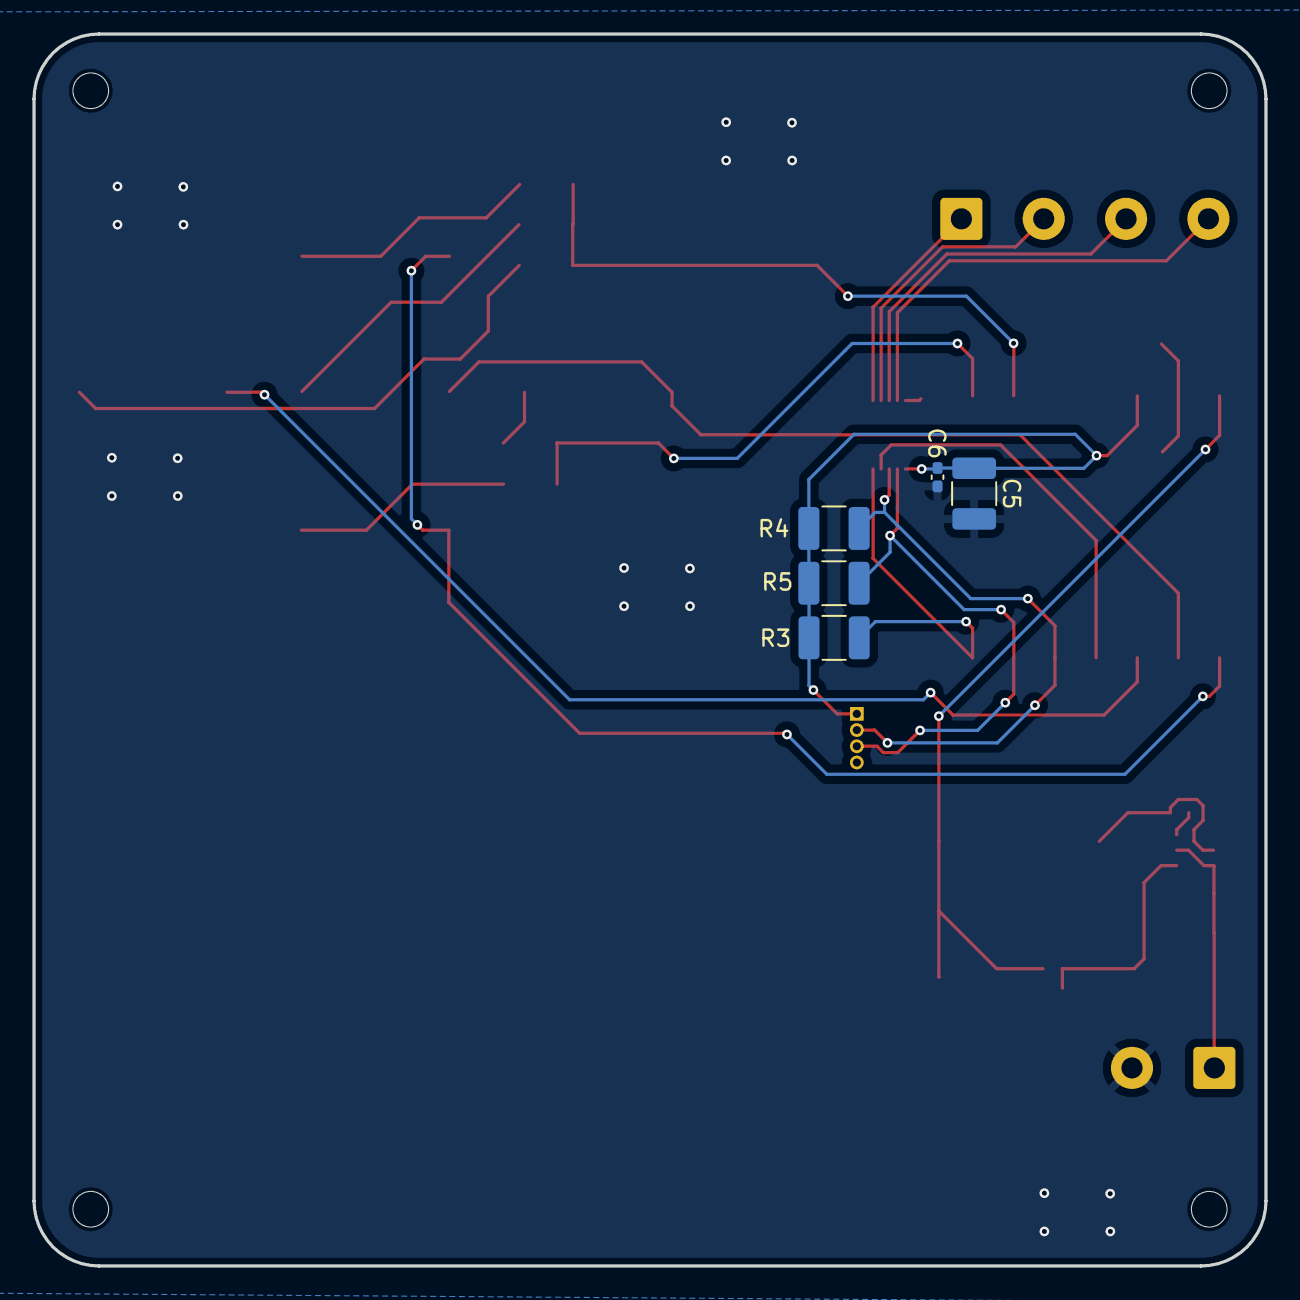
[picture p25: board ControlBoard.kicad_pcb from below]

Board: 2 copper layers, 76.0 x 76.0 mm, 28 parts (5 on the bottom side), 25 nets.

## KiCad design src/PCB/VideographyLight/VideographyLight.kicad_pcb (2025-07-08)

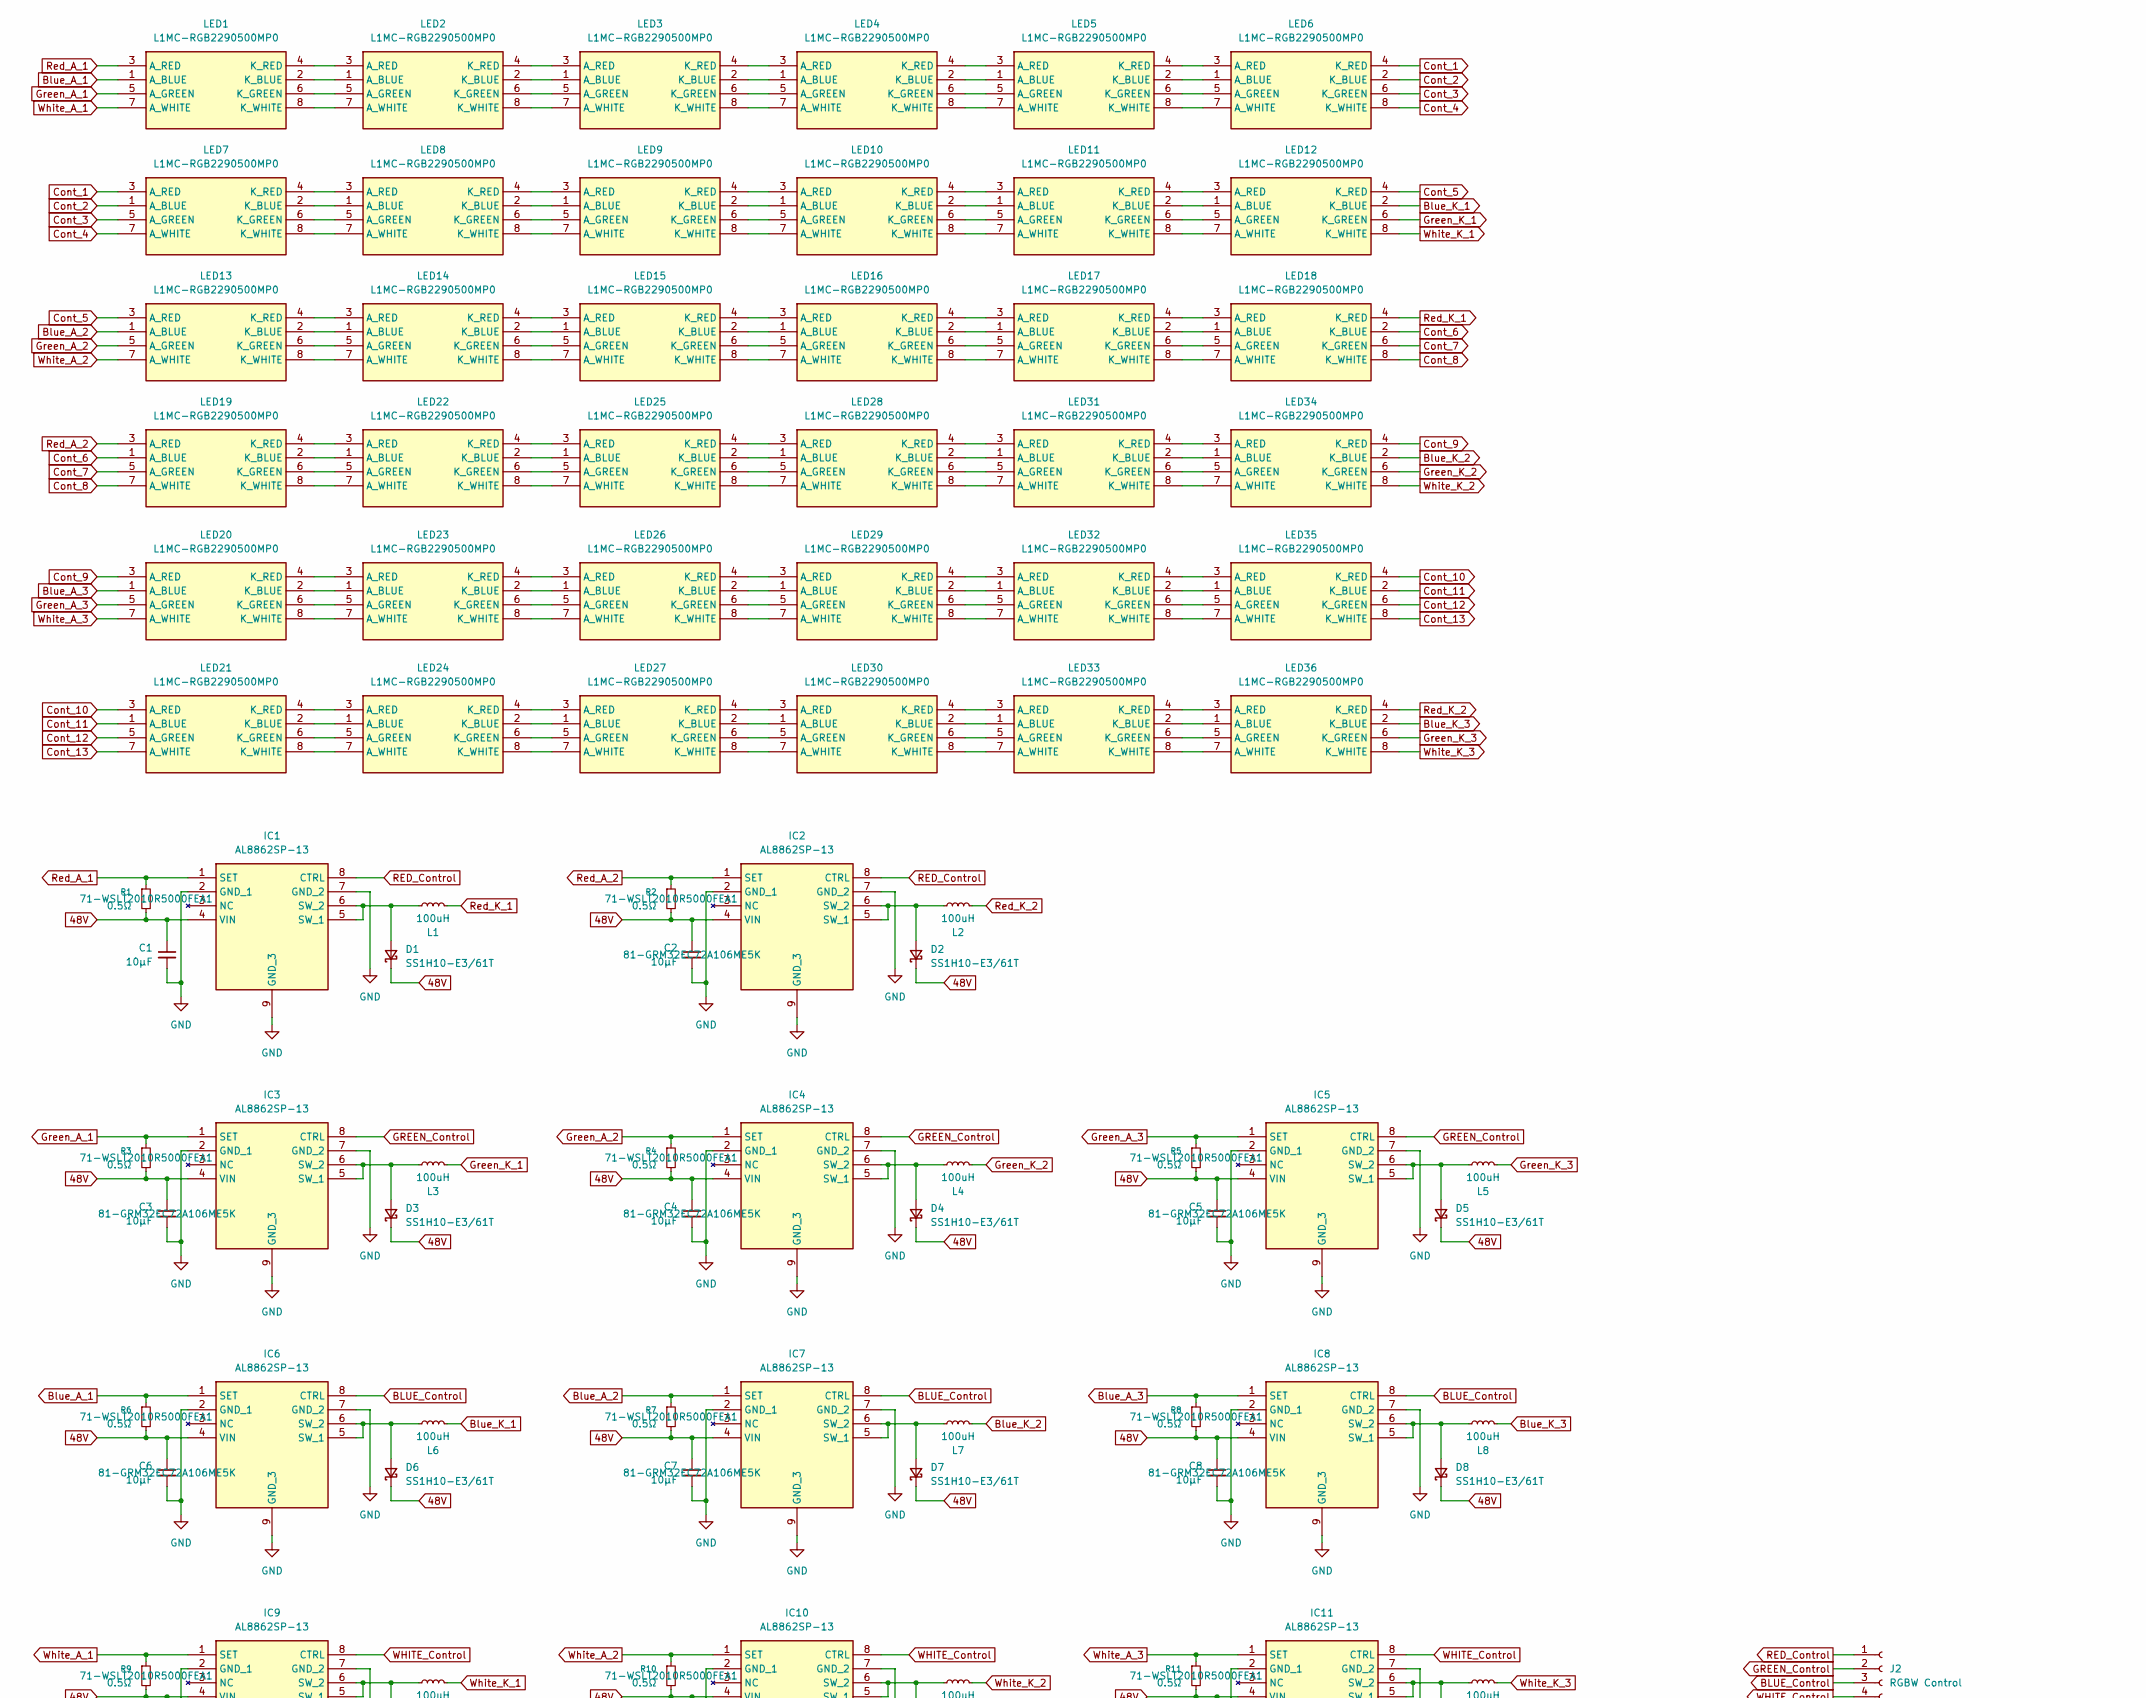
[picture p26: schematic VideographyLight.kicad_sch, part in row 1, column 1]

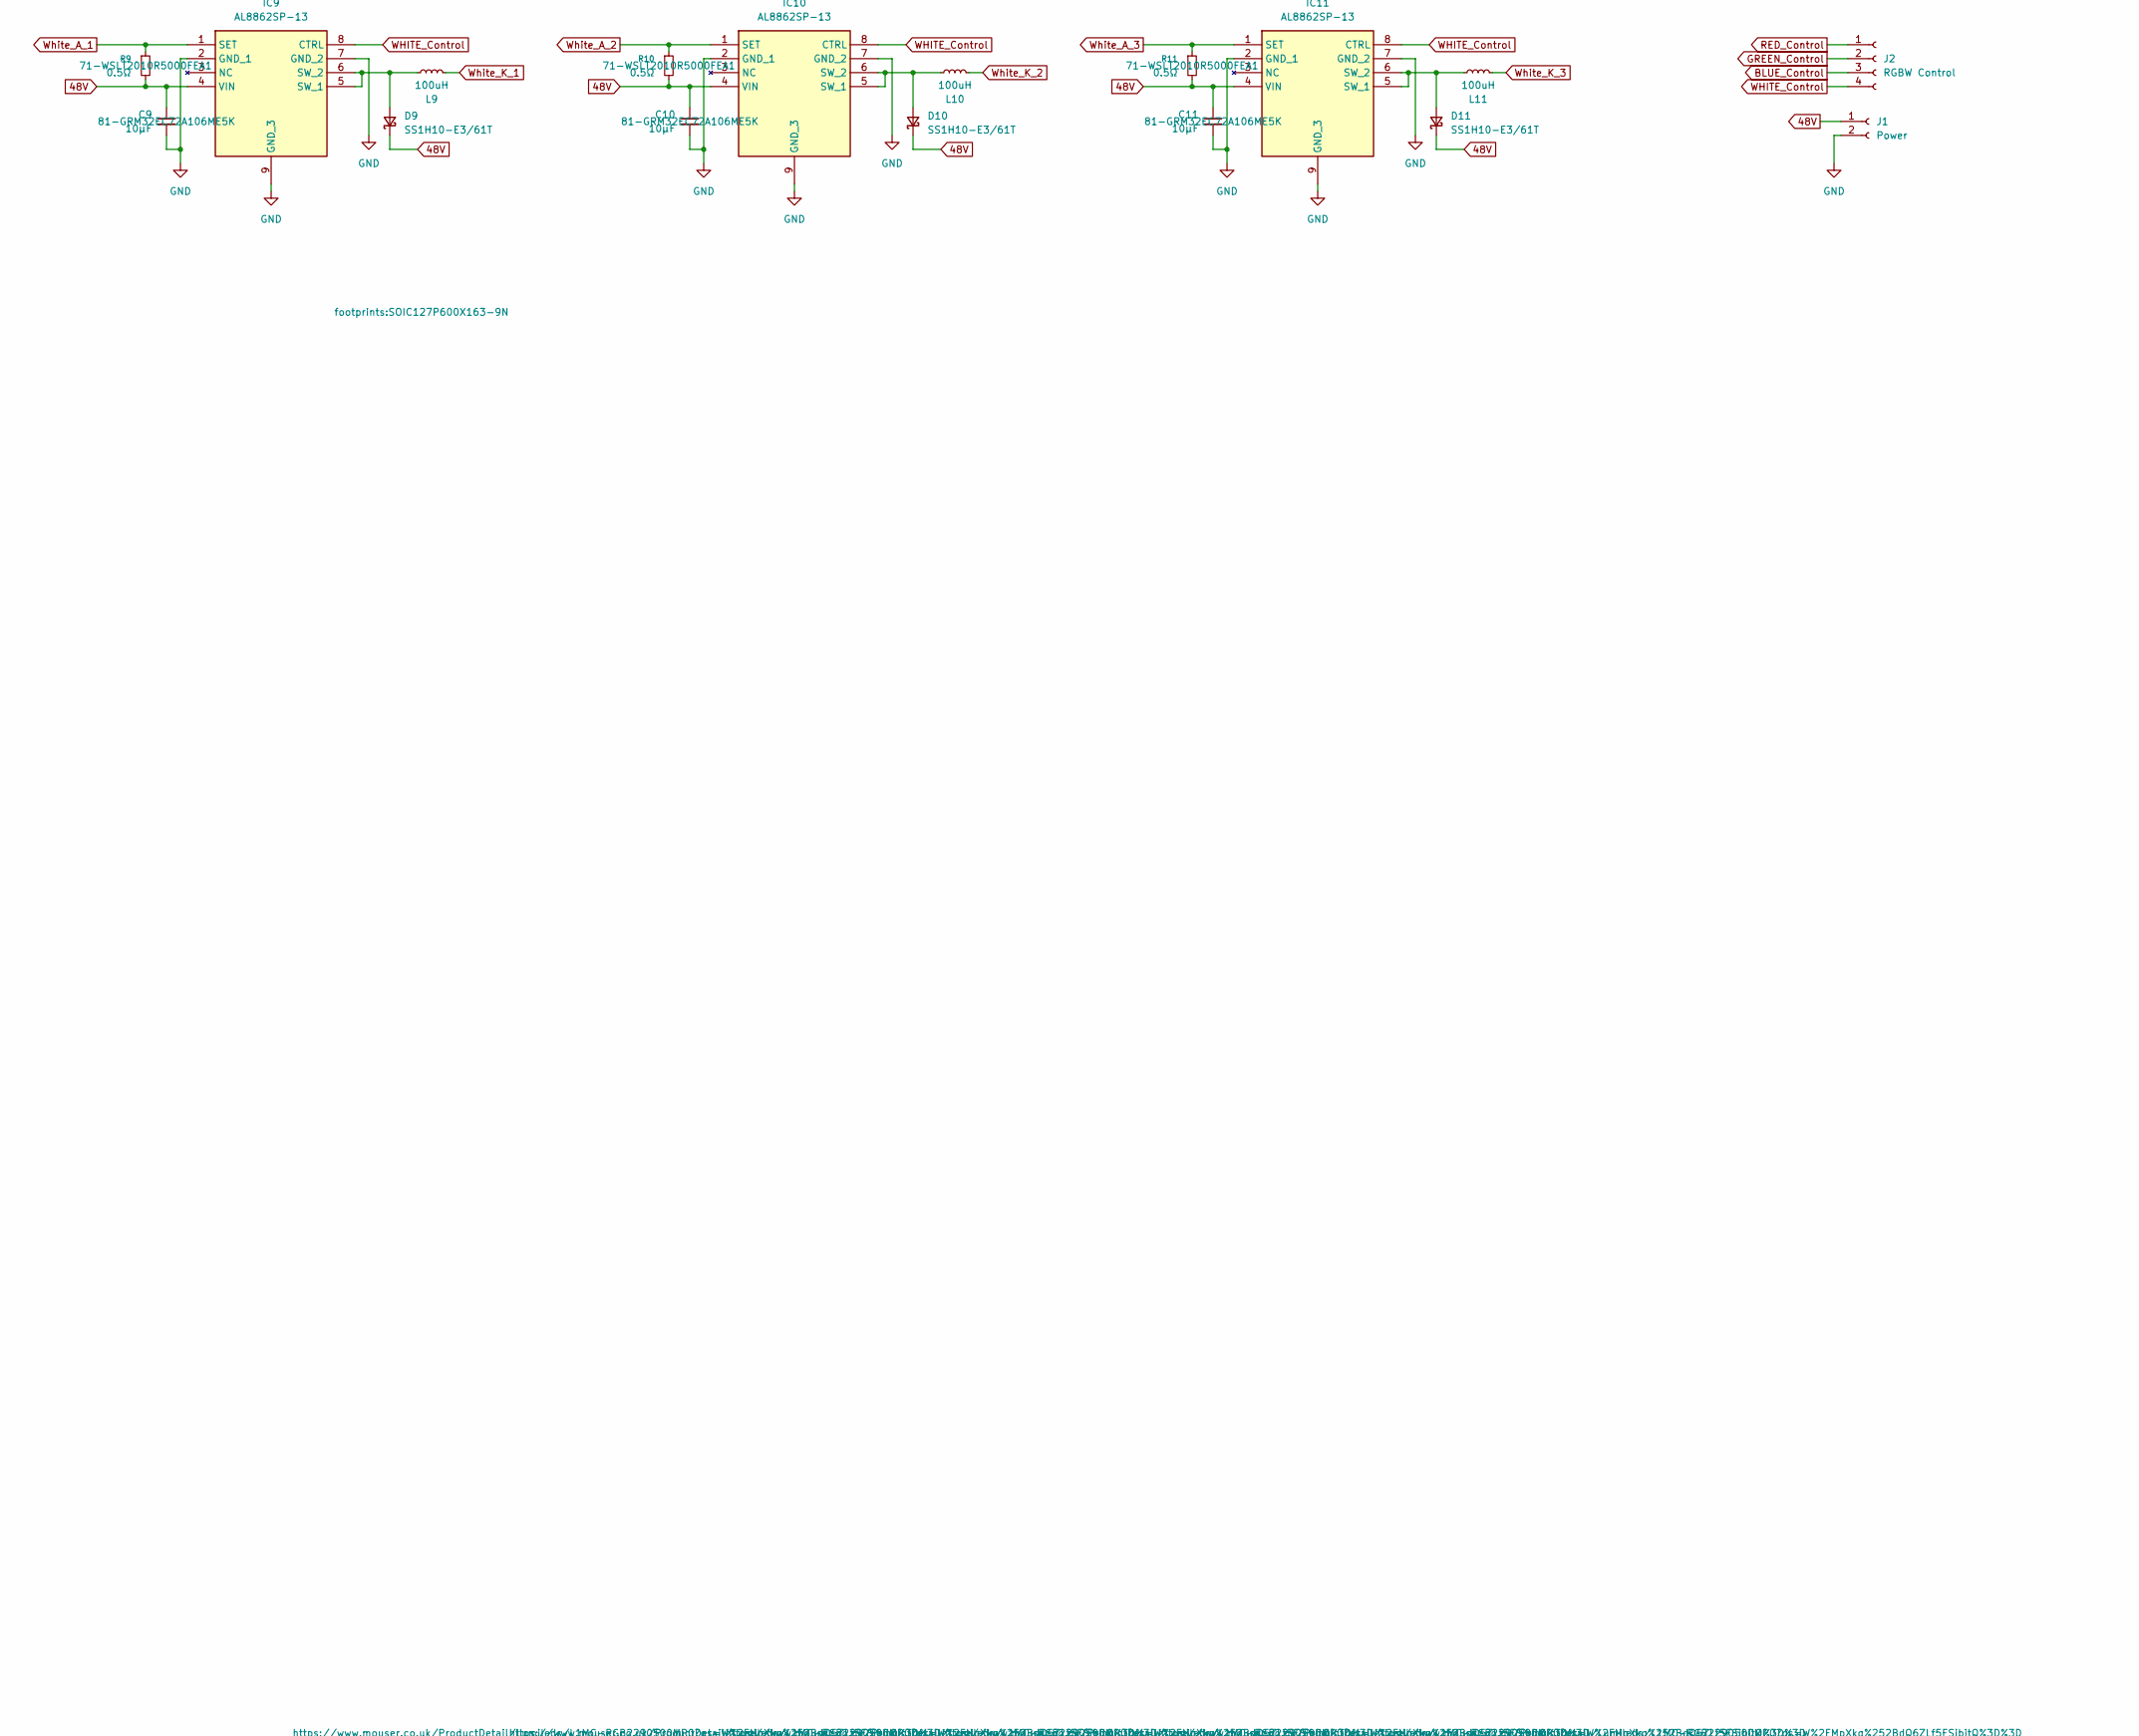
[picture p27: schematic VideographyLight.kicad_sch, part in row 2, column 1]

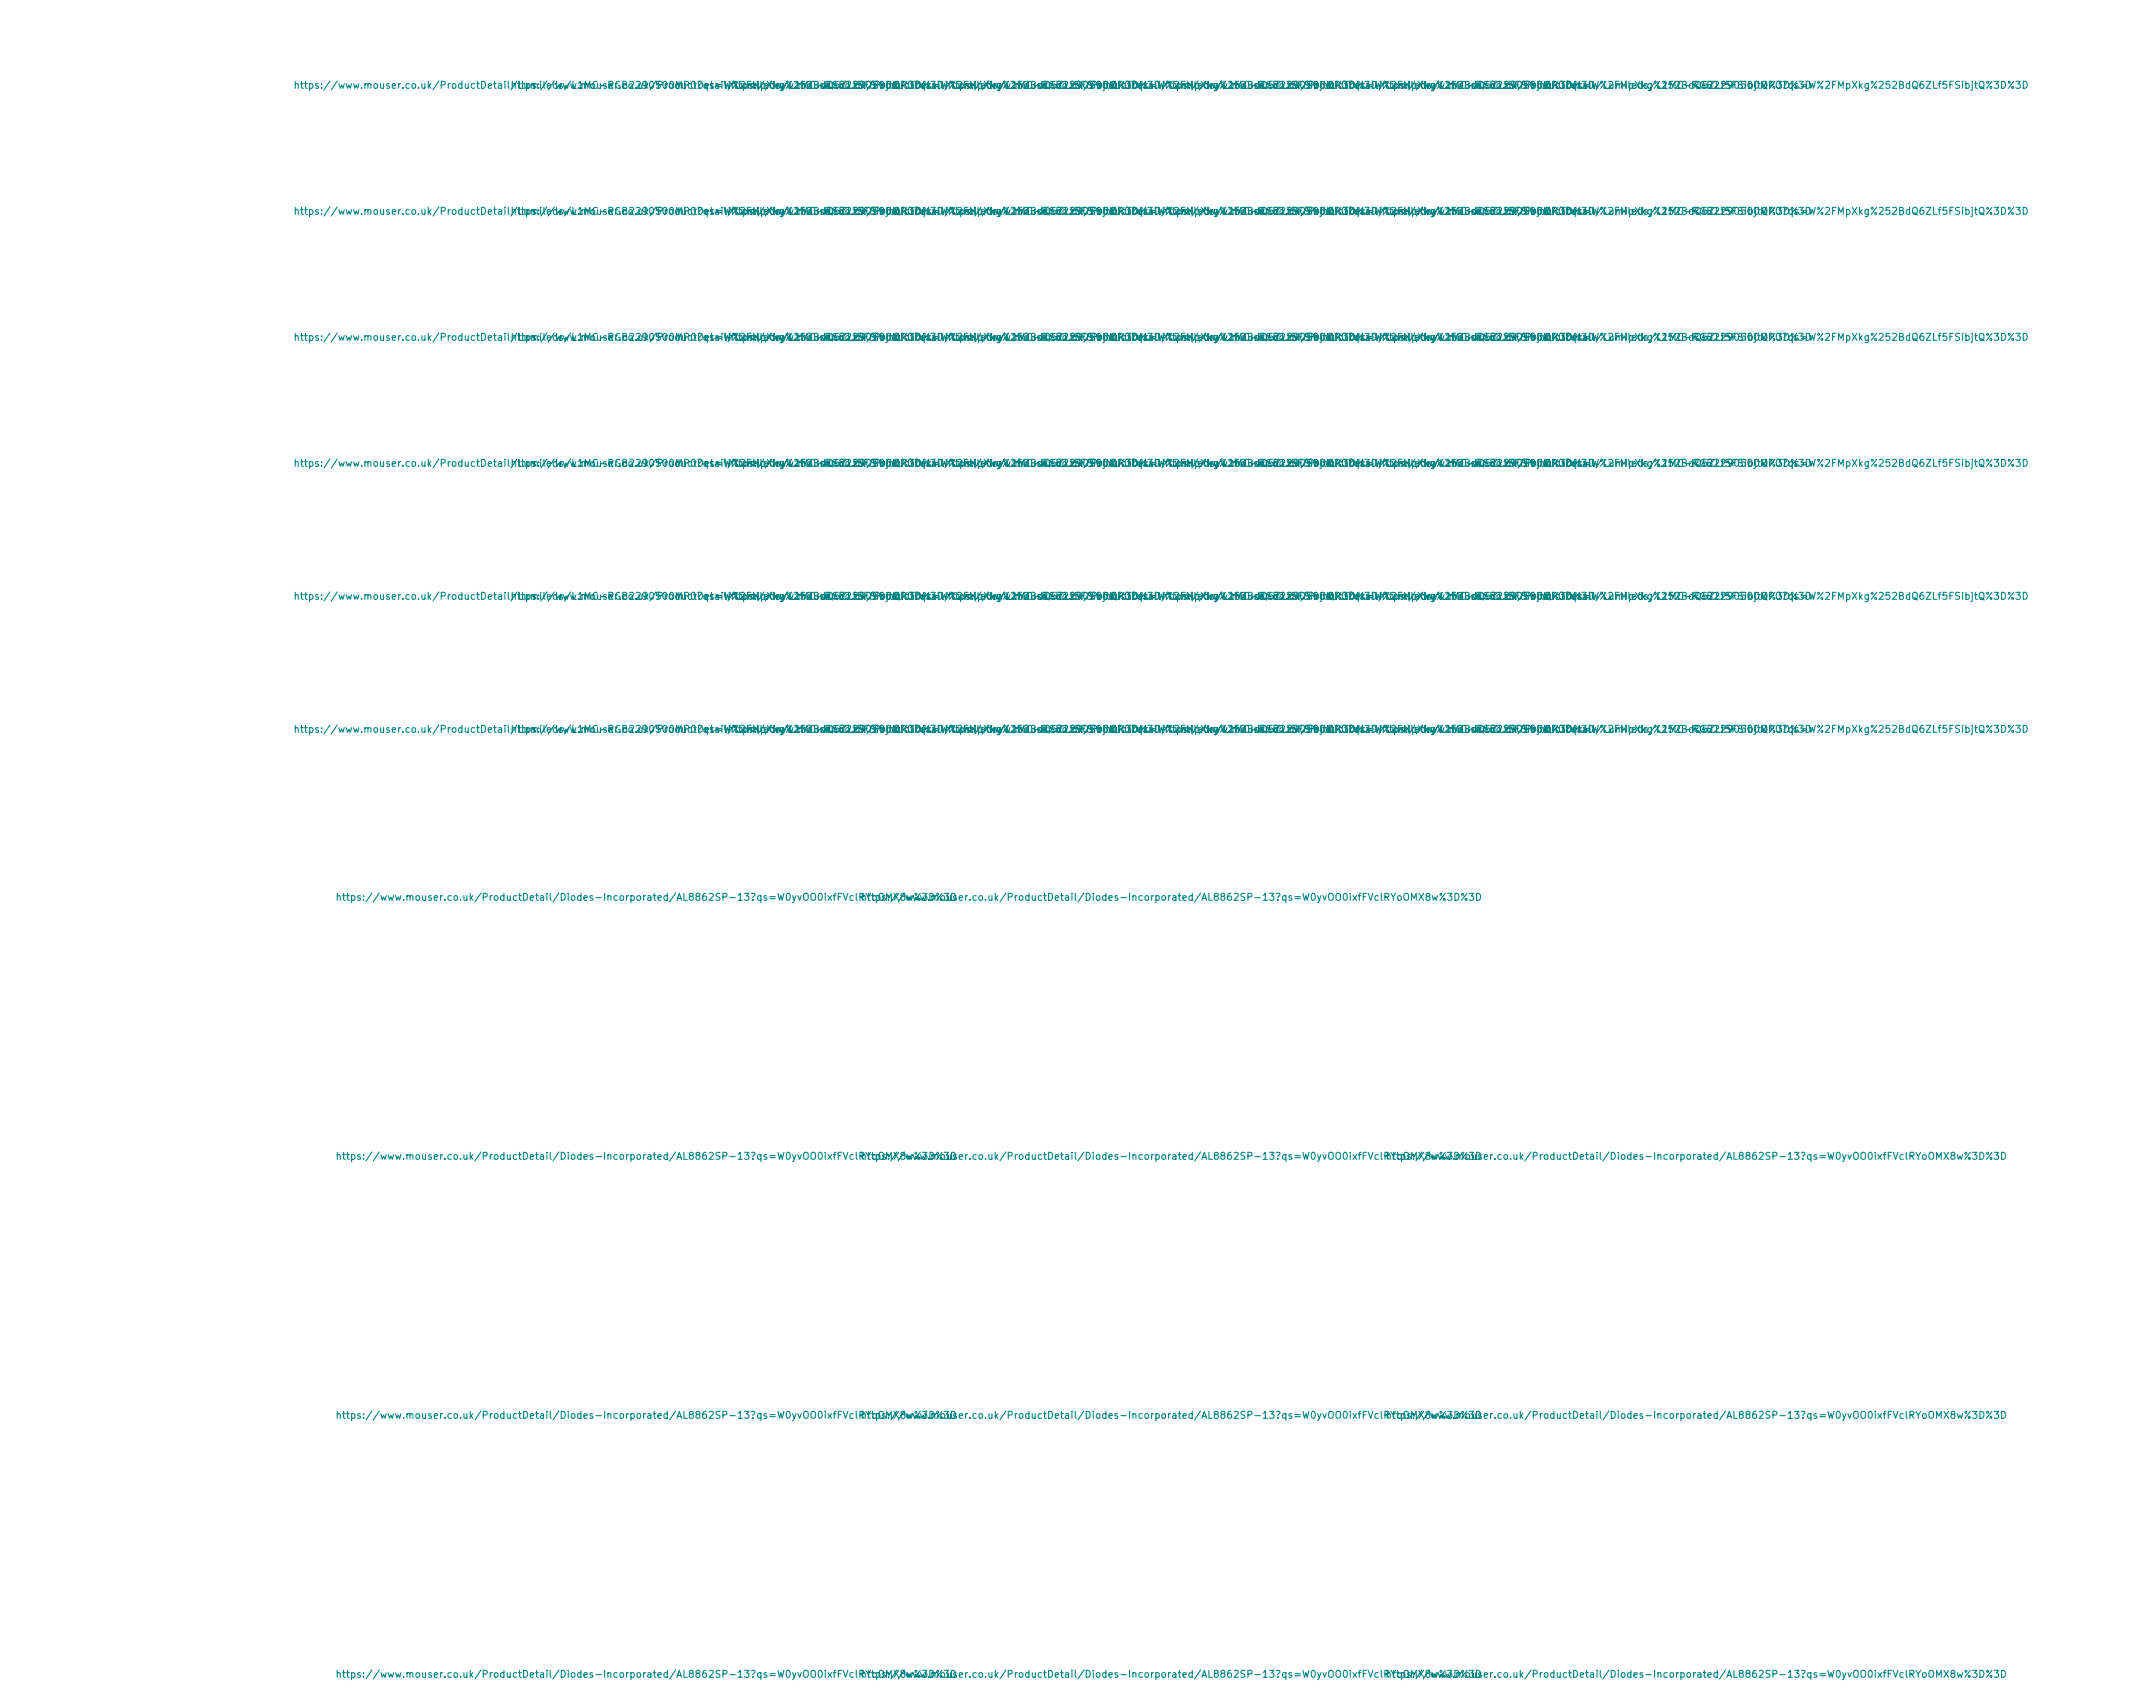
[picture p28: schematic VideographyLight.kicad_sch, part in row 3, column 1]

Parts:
C1, C2, C3, C4, C5, C6, C7, C8, C9, C10, C11: 10μF; C_1210_3225Metric_Pad1.33x2.70mm_HandSolder; Mouser Part Number 81-GRM32EC72A106ME5K
D1, D2, D3, D4, D5, D6, D7, D8, D9, D10, D11: SS1H10-E3/61T; DIOM5127X229N; Mouser Part Number 625-SS1H10-E3
IC1, IC2, IC3, IC4, IC5, IC6, IC7, IC8, IC9, IC10, IC11: AL8862SP-13; SOIC127P600X163-9N; Mouser Part Number 621-AL8862SP-13
J1: Power; TerminalBlock_Phoenix_MKDS-1,5-2-5.08_1x02_P5.08mm_Horizont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; Mouser Part Number 179-TB0012-508-02GR
J2: RGBW Control; TerminalBlock_Phoenix_MKDS-1,5-4-5.08_1x04_P5.08mm_Horizont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; Mouser Part Number 179-TB0012-508-04GR
L1, L2, L3, L4, L5, L6, L7, L8, L9, L10, L11: 100uH; INDPM120120X600N; Mouser Part Number 710-7447706101
LED1, LED2, LED3, LED4, LED5, LED6, LED7, LED8, LED9, LED10, LED11, LED12, LED13, LED14, LED15, LED16, LED17, LED18, LED19, LED20, LED21, LED22, LED23, LED24, LED25, LED26, LED27, LED28, LED29, LED30, LED31, LED32, LED33, LED34, LED35, LED36: L1MC-RGB2290500MP0; L1MCRGB2290500MP0; Mouser Part Number 997-L1MCRGB2295MP0
R1, R2, R3, R4, R5, R6, R7, R8, R9, R10, R11: 0.5Ω; R_2010_5025Metric_Pad1.40x2.65mm_HandSolder; Mouser Part Number 71-WSLT2010R5000FEA1

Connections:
48V: C1.1, C2.1, C3.1, C4.1, C5.1, C6.1, C7.1, C8.1, C9.1, C10.1, C11.1, D1.1 (K), D2.1 (K), D3.1 (K), D4.1 (K), D5.1 (K), D6.1 (K), D7.1 (K), D8.1 (K), D9.1 (K), D10.1 (K), D11.1 (K), IC1.4 (VIN), IC2.4 (VIN), IC3.4 (VIN), IC4.4 (VIN), IC5.4 (VIN), IC6.4 (VIN), IC7.4 (VIN), IC8.4 (VIN), IC9.4 (VIN), IC10.4 (VIN), IC11.4 (VIN), J1.1, R1.2, R2.2, R3.2, R4.2, R5.2, R6.2, R7.2, R8.2, R9.2, R10.2, R11.2
BLUE_Control: IC6.8 (CTRL), IC7.8 (CTRL), IC8.8 (CTRL), J2.3
Blue_A_1: IC6.1 (SET), LED1.1 (A_BLUE), R6.1
Blue_A_2: IC7.1 (SET), LED13.1 (A_BLUE), R7.1
Blue_A_3: IC8.1 (SET), LED20.1 (A_BLUE), R8.1
Blue_K_1: L6.1, LED12.2 (K_BLUE)
Blue_K_2: L7.1, LED34.2 (K_BLUE)
Blue_K_3: L8.1, LED36.2 (K_BLUE)
Cont_1: LED6.4 (K_RED), LED7.3 (A_RED), LED7.9 (A_RED_2)
Cont_2: LED6.2 (K_BLUE), LED7.1 (A_BLUE)
Cont_3: LED6.6 (K_GREEN), LED7.5 (A_GREEN)
Cont_4: LED6.8 (K_WHITE), LED7.7 (A_WHITE)
Cont_5: LED12.4 (K_RED), LED13.3 (A_RED), LED13.9 (A_RED_2)
Cont_6: LED18.2 (K_BLUE), LED19.1 (A_BLUE)
Cont_7: LED18.6 (K_GREEN), LED19.5 (A_GREEN)
Cont_8: LED18.8 (K_WHITE), LED19.7 (A_WHITE)
Cont_9: LED20.3 (A_RED), LED20.9 (A_RED_2), LED34.4 (K_RED)
Cont_10: LED21.3 (A_RED), LED21.9 (A_RED_2), LED35.4 (K_RED)
Cont_11: LED21.1 (A_BLUE), LED35.2 (K_BLUE)
Cont_12: LED21.5 (A_GREEN), LED35.6 (K_GREEN)
Cont_13: LED21.7 (A_WHITE), LED35.8 (K_WHITE)
GND: C1.2, C2.2, C3.2, C4.2, C5.2, C6.2, C7.2, C8.2, C9.2, C10.2, C11.2, IC1.2 (GND_1), IC1.7 (GND_2), IC1.9 (GND_3), IC2.2 (GND_1), IC2.7 (GND_2), IC2.9 (GND_3), IC3.2 (GND_1), IC3.7 (GND_2), IC3.9 (GND_3), IC4.2 (GND_1), IC4.7 (GND_2), IC4.9 (GND_3), IC5.2 (GND_1), IC5.7 (GND_2), IC5.9 (GND_3), IC6.2 (GND_1), IC6.7 (GND_2), IC6.9 (GND_3), IC7.2 (GND_1), IC7.7 (GND_2), IC7.9 (GND_3), IC8.2 (GND_1), IC8.7 (GND_2), IC8.9 (GND_3), IC9.2 (GND_1), IC9.7 (GND_2), IC9.9 (GND_3), IC10.2 (GND_1), IC10.7 (GND_2), IC10.9 (GND_3), IC11.2 (GND_1), IC11.7 (GND_2), IC11.9 (GND_3), J1.2
GREEN_Control: IC3.8 (CTRL), IC4.8 (CTRL), IC5.8 (CTRL), J2.2
Green_A_1: IC3.1 (SET), LED1.5 (A_GREEN), R3.1
Green_A_2: IC4.1 (SET), LED13.5 (A_GREEN), R4.1
Green_A_3: IC5.1 (SET), LED20.5 (A_GREEN), R5.1
Green_K_1: L3.1, LED12.6 (K_GREEN)
Green_K_2: L4.1, LED34.6 (K_GREEN)
Green_K_3: L5.1, LED36.6 (K_GREEN)
unnamed: D1.2 (A), IC1.5 (SW_1), IC1.6 (SW_2), L1.2
unnamed: D2.2 (A), IC2.5 (SW_1), IC2.6 (SW_2), L2.2
unnamed: D3.2 (A), IC3.5 (SW_1), IC3.6 (SW_2), L3.2
unnamed: D4.2 (A), IC4.5 (SW_1), IC4.6 (SW_2), L4.2
unnamed: D5.2 (A), IC5.5 (SW_1), IC5.6 (SW_2), L5.2
unnamed: D6.2 (A), IC6.5 (SW_1), IC6.6 (SW_2), L6.2
unnamed: D7.2 (A), IC7.5 (SW_1), IC7.6 (SW_2), L7.2
unnamed: D8.2 (A), IC8.5 (SW_1), IC8.6 (SW_2), L8.2
unnamed: D9.2 (A), IC9.5 (SW_1), IC9.6 (SW_2), L9.2
unnamed: D10.2 (A), IC10.5 (SW_1), IC10.6 (SW_2), L10.2
unnamed: D11.2 (A), IC11.5 (SW_1), IC11.6 (SW_2), L11.2
unnamed: LED1.2 (K_BLUE), LED2.1 (A_BLUE)
unnamed: LED1.6 (K_GREEN), LED2.5 (A_GREEN)
unnamed: LED1.4 (K_RED), LED2.3 (A_RED), LED2.9 (A_RED_2)
unnamed: LED1.8 (K_WHITE), LED2.7 (A_WHITE)
unnamed: LED2.2 (K_BLUE), LED3.1 (A_BLUE)
unnamed: LED2.6 (K_GREEN), LED3.5 (A_GREEN)
unnamed: LED2.4 (K_RED), LED3.3 (A_RED), LED3.9 (A_RED_2)
unnamed: LED2.8 (K_WHITE), LED3.7 (A_WHITE)
unnamed: LED3.2 (K_BLUE), LED4.1 (A_BLUE)
unnamed: LED3.6 (K_GREEN), LED4.5 (A_GREEN)
unnamed: LED3.4 (K_RED), LED4.3 (A_RED), LED4.9 (A_RED_2)
unnamed: LED3.8 (K_WHITE), LED4.7 (A_WHITE)
unnamed: LED4.2 (K_BLUE), LED5.1 (A_BLUE)
unnamed: LED4.6 (K_GREEN), LED5.5 (A_GREEN)
unnamed: LED4.4 (K_RED), LED5.3 (A_RED), LED5.9 (A_RED_2)
unnamed: LED4.8 (K_WHITE), LED5.7 (A_WHITE)
unnamed: LED5.2 (K_BLUE), LED6.1 (A_BLUE)
unnamed: LED5.6 (K_GREEN), LED6.5 (A_GREEN)
unnamed: LED5.4 (K_RED), LED6.3 (A_RED), LED6.9 (A_RED_2)
unnamed: LED5.8 (K_WHITE), LED6.7 (A_WHITE)
unnamed: LED7.2 (K_BLUE), LED8.1 (A_BLUE)
unnamed: LED7.6 (K_GREEN), LED8.5 (A_GREEN)
unnamed: LED7.4 (K_RED), LED8.3 (A_RED), LED8.9 (A_RED_2)
unnamed: LED7.8 (K_WHITE), LED8.7 (A_WHITE)
unnamed: LED8.2 (K_BLUE), LED9.1 (A_BLUE)
unnamed: LED8.6 (K_GREEN), LED9.5 (A_GREEN)
unnamed: LED8.4 (K_RED), LED9.3 (A_RED), LED9.9 (A_RED_2)
unnamed: LED8.8 (K_WHITE), LED9.7 (A_WHITE)
unnamed: LED9.2 (K_BLUE), LED10.1 (A_BLUE)
unnamed: LED9.6 (K_GREEN), LED10.5 (A_GREEN)
unnamed: LED9.4 (K_RED), LED10.3 (A_RED), LED10.9 (A_RED_2)
unnamed: LED9.8 (K_WHITE), LED10.7 (A_WHITE)
unnamed: LED10.2 (K_BLUE), LED11.1 (A_BLUE)
unnamed: LED10.6 (K_GREEN), LED11.5 (A_GREEN)
unnamed: LED10.4 (K_RED), LED11.3 (A_RED), LED11.9 (A_RED_2)
unnamed: LED10.8 (K_WHITE), LED11.7 (A_WHITE)
unnamed: LED11.2 (K_BLUE), LED12.1 (A_BLUE)
unnamed: LED11.6 (K_GREEN), LED12.5 (A_GREEN)
unnamed: LED11.4 (K_RED), LED12.3 (A_RED), LED12.9 (A_RED_2)
unnamed: LED11.8 (K_WHITE), LED12.7 (A_WHITE)
unnamed: LED13.2 (K_BLUE), LED14.1 (A_BLUE)
unnamed: LED13.6 (K_GREEN), LED14.5 (A_GREEN)
unnamed: LED13.4 (K_RED), LED14.3 (A_RED), LED14.9 (A_RED_2)
unnamed: LED13.8 (K_WHITE), LED14.7 (A_WHITE)
unnamed: LED14.2 (K_BLUE), LED15.1 (A_BLUE)
unnamed: LED14.6 (K_GREEN), LED15.5 (A_GREEN)
unnamed: LED14.4 (K_RED), LED15.3 (A_RED), LED15.9 (A_RED_2)
unnamed: LED14.8 (K_WHITE), LED15.7 (A_WHITE)
unnamed: LED15.2 (K_BLUE), LED16.1 (A_BLUE)
unnamed: LED15.6 (K_GREEN), LED16.5 (A_GREEN)
unnamed: LED15.4 (K_RED), LED16.3 (A_RED), LED16.9 (A_RED_2)
unnamed: LED15.8 (K_WHITE), LED16.7 (A_WHITE)
unnamed: LED16.2 (K_BLUE), LED17.1 (A_BLUE)
unnamed: LED16.6 (K_GREEN), LED17.5 (A_GREEN)
unnamed: LED16.4 (K_RED), LED17.3 (A_RED), LED17.9 (A_RED_2)
unnamed: LED16.8 (K_WHITE), LED17.7 (A_WHITE)
unnamed: LED17.2 (K_BLUE), LED18.1 (A_BLUE)
unnamed: LED17.6 (K_GREEN), LED18.5 (A_GREEN)
unnamed: LED17.4 (K_RED), LED18.3 (A_RED), LED18.9 (A_RED_2)
unnamed: LED17.8 (K_WHITE), LED18.7 (A_WHITE)
unnamed: LED19.2 (K_BLUE), LED22.1 (A_BLUE)
unnamed: LED19.6 (K_GREEN), LED22.5 (A_GREEN)
unnamed: LED19.4 (K_RED), LED22.3 (A_RED), LED22.9 (A_RED_2)
unnamed: LED19.8 (K_WHITE), LED22.7 (A_WHITE)
unnamed: LED20.2 (K_BLUE), LED23.1 (A_BLUE)
unnamed: LED20.6 (K_GREEN), LED23.5 (A_GREEN)
unnamed: LED20.4 (K_RED), LED23.3 (A_RED), LED23.9 (A_RED_2)
unnamed: LED20.8 (K_WHITE), LED23.7 (A_WHITE)
unnamed: LED21.2 (K_BLUE), LED24.1 (A_BLUE)
unnamed: LED21.6 (K_GREEN), LED24.5 (A_GREEN)
unnamed: LED21.4 (K_RED), LED24.3 (A_RED), LED24.9 (A_RED_2)
unnamed: LED21.8 (K_WHITE), LED24.7 (A_WHITE)
unnamed: LED22.2 (K_BLUE), LED25.1 (A_BLUE)
unnamed: LED22.6 (K_GREEN), LED25.5 (A_GREEN)
unnamed: LED22.4 (K_RED), LED25.3 (A_RED), LED25.9 (A_RED_2)
unnamed: LED22.8 (K_WHITE), LED25.7 (A_WHITE)
unnamed: LED23.2 (K_BLUE), LED26.1 (A_BLUE)
unnamed: LED23.6 (K_GREEN), LED26.5 (A_GREEN)
unnamed: LED23.4 (K_RED), LED26.3 (A_RED), LED26.9 (A_RED_2)
unnamed: LED23.8 (K_WHITE), LED26.7 (A_WHITE)
unnamed: LED24.2 (K_BLUE), LED27.1 (A_BLUE)
unnamed: LED24.6 (K_GREEN), LED27.5 (A_GREEN)
unnamed: LED24.4 (K_RED), LED27.3 (A_RED), LED27.9 (A_RED_2)
unnamed: LED24.8 (K_WHITE), LED27.7 (A_WHITE)
unnamed: LED25.2 (K_BLUE), LED28.1 (A_BLUE)
unnamed: LED25.6 (K_GREEN), LED28.5 (A_GREEN)
unnamed: LED25.4 (K_RED), LED28.3 (A_RED), LED28.9 (A_RED_2)
unnamed: LED25.8 (K_WHITE), LED28.7 (A_WHITE)
unnamed: LED26.2 (K_BLUE), LED29.1 (A_BLUE)
unnamed: LED26.6 (K_GREEN), LED29.5 (A_GREEN)
unnamed: LED26.4 (K_RED), LED29.3 (A_RED), LED29.9 (A_RED_2)
unnamed: LED26.8 (K_WHITE), LED29.7 (A_WHITE)
unnamed: LED27.2 (K_BLUE), LED30.1 (A_BLUE)
unnamed: LED27.6 (K_GREEN), LED30.5 (A_GREEN)
unnamed: LED27.4 (K_RED), LED30.3 (A_RED), LED30.9 (A_RED_2)
unnamed: LED27.8 (K_WHITE), LED30.7 (A_WHITE)
unnamed: LED28.2 (K_BLUE), LED31.1 (A_BLUE)
unnamed: LED28.6 (K_GREEN), LED31.5 (A_GREEN)
unnamed: LED28.4 (K_RED), LED31.3 (A_RED), LED31.9 (A_RED_2)
unnamed: LED28.8 (K_WHITE), LED31.7 (A_WHITE)
unnamed: LED29.2 (K_BLUE), LED32.1 (A_BLUE)
unnamed: LED29.6 (K_GREEN), LED32.5 (A_GREEN)
unnamed: LED29.4 (K_RED), LED32.3 (A_RED), LED32.9 (A_RED_2)
unnamed: LED29.8 (K_WHITE), LED32.7 (A_WHITE)
unnamed: LED30.2 (K_BLUE), LED33.1 (A_BLUE)
unnamed: LED30.6 (K_GREEN), LED33.5 (A_GREEN)
unnamed: LED30.4 (K_RED), LED33.3 (A_RED), LED33.9 (A_RED_2)
unnamed: LED30.8 (K_WHITE), LED33.7 (A_WHITE)
unnamed: LED31.2 (K_BLUE), LED34.1 (A_BLUE)
unnamed: LED31.6 (K_GREEN), LED34.5 (A_GREEN)
unnamed: LED31.4 (K_RED), LED34.3 (A_RED), LED34.9 (A_RED_2)
unnamed: LED31.8 (K_WHITE), LED34.7 (A_WHITE)
unnamed: LED32.2 (K_BLUE), LED35.1 (A_BLUE)
unnamed: LED32.6 (K_GREEN), LED35.5 (A_GREEN)
unnamed: LED32.4 (K_RED), LED35.3 (A_RED), LED35.9 (A_RED_2)
unnamed: LED32.8 (K_WHITE), LED35.7 (A_WHITE)
unnamed: LED33.2 (K_BLUE), LED36.1 (A_BLUE)
unnamed: LED33.6 (K_GREEN), LED36.5 (A_GREEN)
unnamed: LED33.4 (K_RED), LED36.3 (A_RED), LED36.9 (A_RED_2)
unnamed: LED33.8 (K_WHITE), LED36.7 (A_WHITE)
RED_Control: IC1.8 (CTRL), IC2.8 (CTRL), J2.1
Red_A_1: IC1.1 (SET), LED1.3 (A_RED), LED1.9 (A_RED_2), R1.1
Red_A_2: IC2.1 (SET), LED19.3 (A_RED), LED19.9 (A_RED_2), R2.1
Red_K_1: L1.1, LED18.4 (K_RED)
Red_K_2: L2.1, LED36.4 (K_RED)
WHITE_Control: IC9.8 (CTRL), IC10.8 (CTRL), IC11.8 (CTRL), J2.4
White_A_1: IC9.1 (SET), LED1.7 (A_WHITE), R9.1
White_A_2: IC10.1 (SET), LED13.7 (A_WHITE), R10.1
White_A_3: IC11.1 (SET), LED20.7 (A_WHITE), R11.1
White_K_1: L9.1, LED12.8 (K_WHITE)
White_K_2: L10.1, LED34.8 (K_WHITE)
White_K_3: L11.1, LED36.8 (K_WHITE)

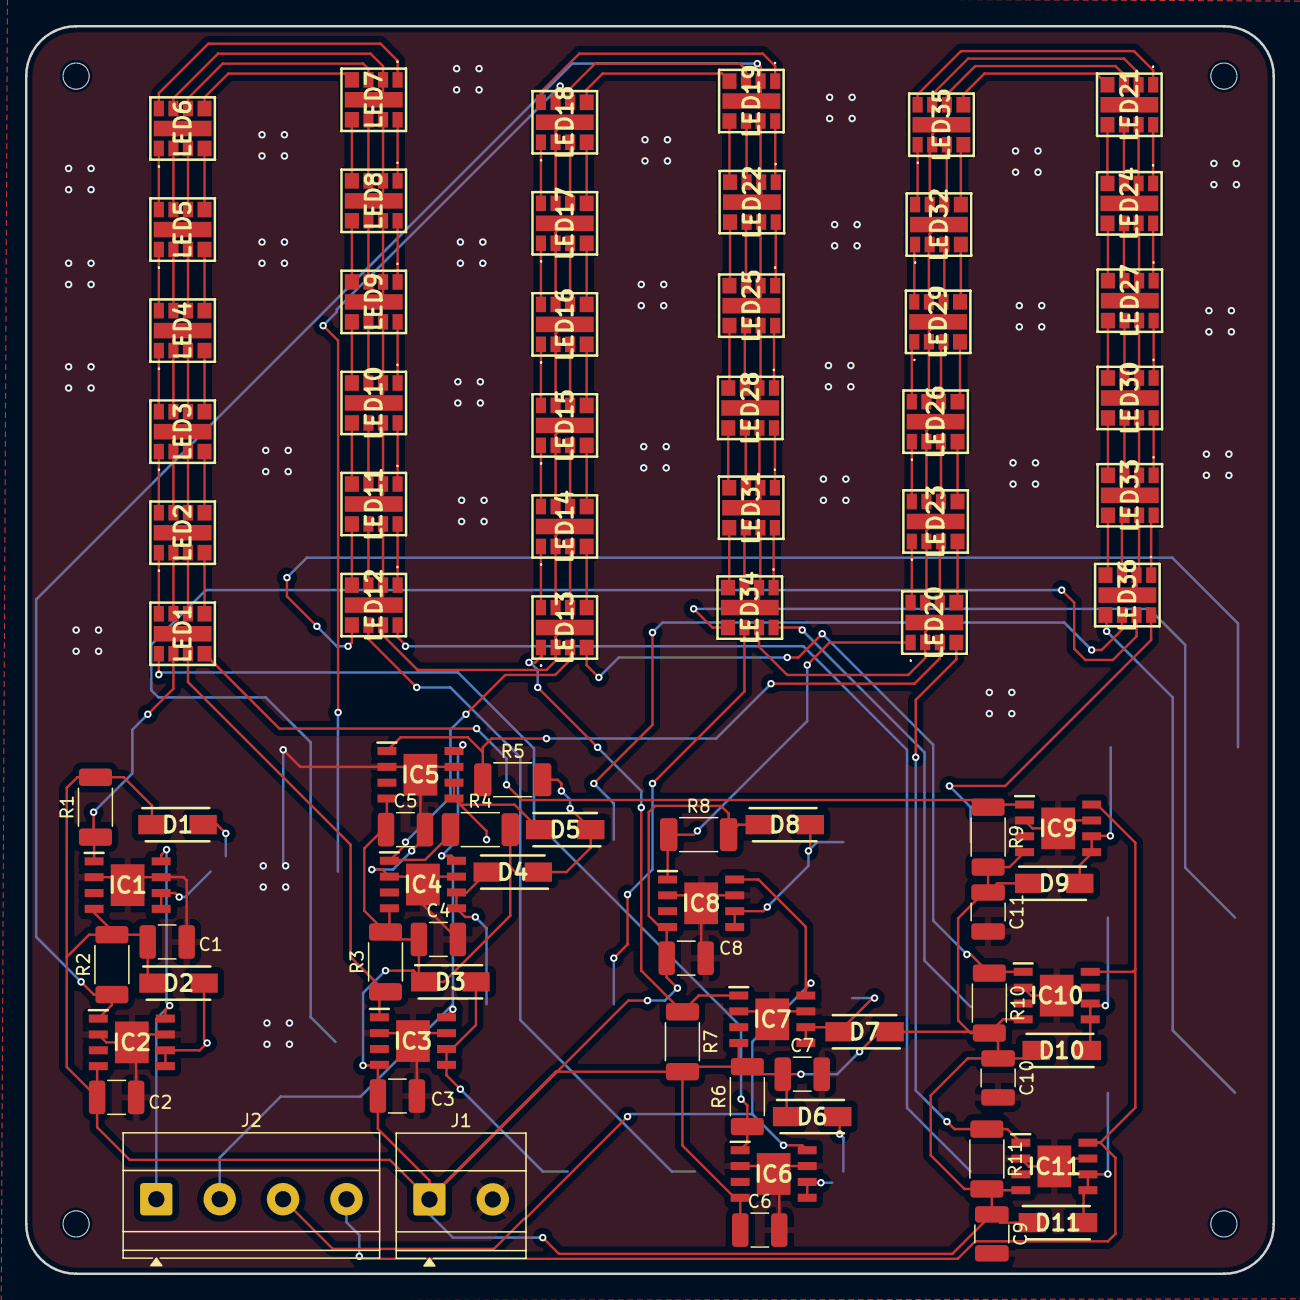
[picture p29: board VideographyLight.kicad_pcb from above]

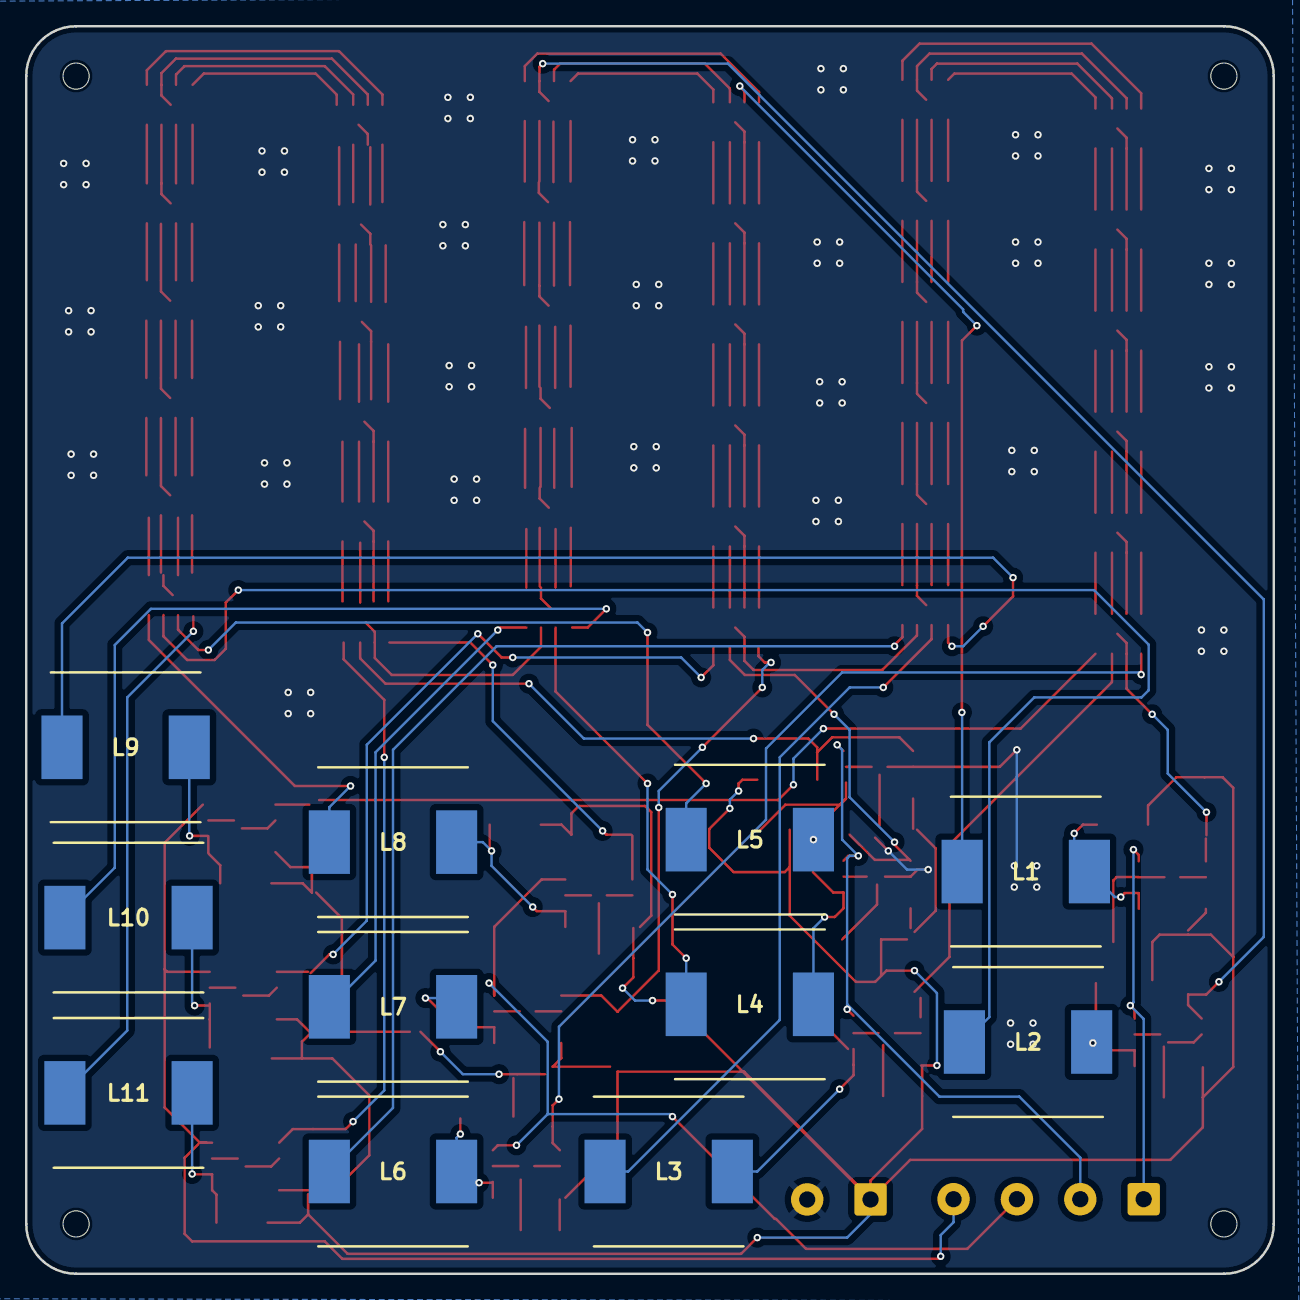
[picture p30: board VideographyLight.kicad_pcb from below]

Board: 2 copper layers, 100.0 x 100.0 mm, 93 parts (11 on the bottom side), 172 nets.

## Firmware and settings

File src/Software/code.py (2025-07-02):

import time
import board
import keypad

import busio
import digitalio
import displayio
import terminalio

import adafruit_mcp4728
import adafruit_displayio_ssd1306

from adafruit_display_text import label


# I2C pins
SCL_PIN = board.SCL  # D5 / GPIO7
SDA_PIN = board.SDA  # D4 / GPIO6

# I2C addresses (7 bit addresses)
OLED_I2C_ADDR = 0x3C
DAC_I2C_ADDR = 0x60

# DAC pins
LDAC_PIN = board.A3  # GPIO29 - LDAC pin (must be held low to update DAC outputs immediately)
RDY_PIN = board.D6   # GPIO0 - RDY/BSY pin (indicates EEPROM write status, not used but pulled up)

# Button matrix pins
COL_PINS = (board.A0, board.A1, board.A2)
ROW_PINS = (board.D8, board.D7)

# Display dimensions
SCREEN_WIDTH = 128
SCREEN_HEIGHT = 64

# DAC output configuration
# Output range is from 0V to 3.3V (rail-to-rail)
# Output should be between 0.4V to 2.5V
# Output values are 16-bit in CircuitPython (0-65535)
MIN_DAC_VAL = int((0.4 / 3.3) * 65535)
MAX_DAC_VAL = int((2.5 / 3.3) * 65535)
OFF_DAC_VAL = 0

def brightness_to_dac(percent):
    """Converts a 0-100% brightness value to a 16-bit DAC value."""
    if percent <= 0:
        return OFF_DAC_VAL
    if percent >= 100:
        return MAX_DAC_VAL
    return MIN_DAC_VAL + int(((percent - 1) / 99.0) * (MAX_DAC_VAL - MIN_DAC_VAL))


# Initialise Display
displayio.release_displays()

# Initialise I2C bus
i2c = busio.I2C(SCL_PIN, SDA_PIN)

# Initialise DAC LDAC and RDY pins
ldac = digitalio.DigitalInOut(LDAC_PIN)
ldac.direction = digitalio.Direction.OUTPUT
ldac.value = False

rdy = digitalio.DigitalInOut(RDY_PIN)
rdy.direction = digitalio.Direction.INPUT
rdy.pull = digitalio.Pull.UP

# Initialise DAC and Display
display_bus = displayio.I2CDisplay(i2c, device_address=OLED_I2C_ADDR)
display = adafruit_displayio_ssd1306.SSD1306(display_bus, width=SCREEN_WIDTH, height=SCREEN_HEIGHT)

dac = adafruit_mcp4728.MCP4728(i2c, address=DAC_I2C_ADDR)

# Initialise button matrix
key_matrix = keypad.KeyMatrix(
    row_pins=ROW_PINS,
    column_pins=COL_PINS,
    columns_to_anodes=True
)
key_name_map = {0: "UP", 1: "SELECT", 2: "RIGHT", 3: "DOWN", 4: "LEFT"}

# Create a display group
ui_group = displayio.Group()
ui_labels = []

for i in range(1, 5):
    # Channel Name (eg. "> Ch A:")
    ch_label = label.Label(terminalio.FONT, text="", x=2, y=i * 16)
    ui_group.append(ch_label)

    # Percentage Value (e.g., "100%")
    val_label = label.Label(terminalio.FONT, text="", x=62, y=i * 16)
    ui_group.append(val_label)

    ui_labels.append((ch_label, val_label))

display.root_group = ui_group

def update_ui(brightness_levels, selected_channel):
    """Renders the user interface on the OLED display."""
    for i in range(4):
        selector = ">" if i == selected_channel else " "
        ch_name = chr(ord('A') + i)
        percent = brightness_levels[i]
        
        ui_labels[i][0].text = f"{selector}Ch {ch_name}:"
        ui_labels[i][1].text = f"{percent:3d}%"

# Ininitialise lights
brightness_levels = [20, 20, 20, 20]  # 0-100% for 4 channels
selected_channel = 0

# Set all channels to initial brightness
for i in range(4):
    dac_val = brightness_to_dac(brightness_levels[i])
    channel = getattr(dac, f'channel_{chr(ord("a") + i)}')
    channel.value = dac_val

update_ui(brightness_levels, selected_channel)

# Moved out of main loop for efficiency
key_name = None

# Main loop
while True:
    event = key_matrix.events.get()
    state_changed = False

    if event and event.pressed:
        key_name = key_name_map.get(event.key_number)

        if key_name == "UP":
            selected_channel = (selected_channel - 1) % 4
            state_changed = True
        elif key_name == "DOWN":
            selected_channel = (selected_channel + 1) % 4
            state_changed = True
        elif key_name == "RIGHT":
            brightness_levels[selected_channel] = min(100, brightness_levels[selected_channel] + 4)
            state_changed = True
        elif key_name == "LEFT":
            brightness_levels[selected_channel] = max(0, brightness_levels[selected_channel] - 4)
            state_changed = True
        elif key_name == "SELECT":
            # Toggle between 0% and 100% for quick on/off
            brightness_levels[selected_channel] = 100 if brightness_levels[selected_channel] == 0 else 0
            state_changed = True

    if state_changed and key_name in ["RIGHT", "LEFT", "SELECT"]:
        # Only update the DAC if brightness changed
        dac_val = brightness_to_dac(brightness_levels[selected_channel])
        channel = getattr(dac, f'channel_{chr(ord("a") + selected_channel)}')
        channel.value = dac_val
        
        # Update the display
        update_ui(brightness_levels, selected_channel)

    time.sleep(0.02)

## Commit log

2025-07-01 Initial Upload
    [VideographyLight.kicad_pcb, VideographyLight.kicad_sch]
2025-07-02 Add Kicad .gitignore
2025-07-02 Upload Control Board
    Add initial project files and setup.
    [ControlBoard.kicad_pcb, ControlBoard.kicad_sch]
2025-07-02 Rearrange Files
    [VideographyLight.kicad_pcb, VideographyLight.kicad_sch]
2025-07-02 Add Control Board Exports
2025-07-03 Push model for CAD
    [TEMPVideographyLight.f3d, VideographyLight.kicad_pcb, VideographyLight.kicad_sch]
2025-07-07 Upload Light PCB
    [TEMPVideographyLight.f3d, VideographyLight.kicad_pcb, VideographyLight.kicad_sch]
2025-07-07 Add 3D Print Case STEP Files
    [BasePrint.step, ShellPrint.step]
2025-07-07 Update BOM export for Control Board
2025-07-07 Update BOM
    [ControlBoard.csv, VideographyLight.csv]
2025-07-07 Update Case Design
    [BasePrint.step, ShellPrint.step]
2025-07-07 Upload completed BOM
    [BOM.csv]
2025-07-07 Add Wiring Diagram to README
2025-07-07 Add screen location and power hole to case design
    [BasePrint.step, ShellPrint.step]
2025-07-07 Fix BOM
    [BOM.csv]
2025-07-08 Add case journal entry
2025-07-08 Add case sketch image
2025-07-08 Upload images for silkscreen
2025-07-08 Add case render image
2025-07-08 Finalise PCB and upload gerbers
    [AL8862SP-13.stp, ControlBoard.kicad_pcb, SS1H10-E3_61T.stp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]
2025-07-08 Add CAD to README
